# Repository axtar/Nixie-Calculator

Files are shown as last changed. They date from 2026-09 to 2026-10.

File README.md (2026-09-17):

## Nixie Calculator - RPN | Algebraic 

<br>

#### This repository contains some information and ideas for building a nixie calculator and is provided *as-is* for educational, experimental, and hobbyist purposes only. However, this repository is only intended for suitably qualified electronics engineers. The project has not been tested for compliance with electrical, safety, or electromagnetic standards (e.g., CE, FCC). 

##
>[!WARNING]
> 
> #### Nixie tubes and associated circuitry operate at potentially dangerous voltages. If you choose to build or use the calculator, you are doing so at your own risk.

>[!IMPORTANT]
>- **Start with [this document](Docs/README.md).**

>[!NOTE]
> - **The project is not affiliated with any of the service providers mentioned in this repository.**
> - **No HP code was used to develop the RPN firmware.**

##
#### Project Status 
- **Software: ready to be reviewed**
- **Hardware: ready to be reviewed**

#### Project video
https://www.youtube.com/watch?v=CKAuJhKjPZ4

#### Features
-	4 nixie versions: IN-12/IN-15A, IN-16, IN-17 and B-5870
-	alternative 7-segment LED version 
-	2 calculator engines: RPN (reverse polish notation) or algebraic
- 14 digits with decimal points, minus signs and dynamic scientific notation
-	arbitrary-precision arithmetic up to 32 digits (experimental)
-	30+ math operations
-	easy nixie replacement
- LED backlighting/underlighting (nixie versions only)
-	mechanical keyboard with 40 switches
-	custom keycap legends and colors
-	RTC with battery backup
-	clock, stopwatch and timer modes
-	ESP32 based controller board
-	PIR, GPS and temperature sensor module (optional)
-	works with a standard DC 12V/2A regulated power supply (wall wart)
-	3D printed case
-	no network connection is needed; all settings can be adjusted using the keyboard
- Optional web based features: configuration, device mirroring and stack register display
-	open-source firmware

#### RPN IN-16 version
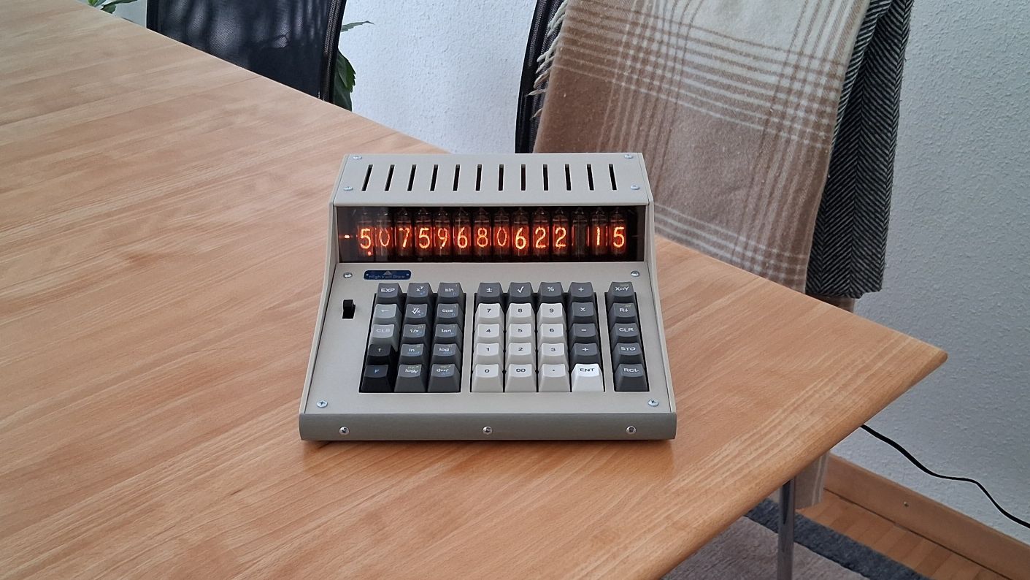
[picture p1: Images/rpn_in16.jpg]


#### RPN IN-17 version
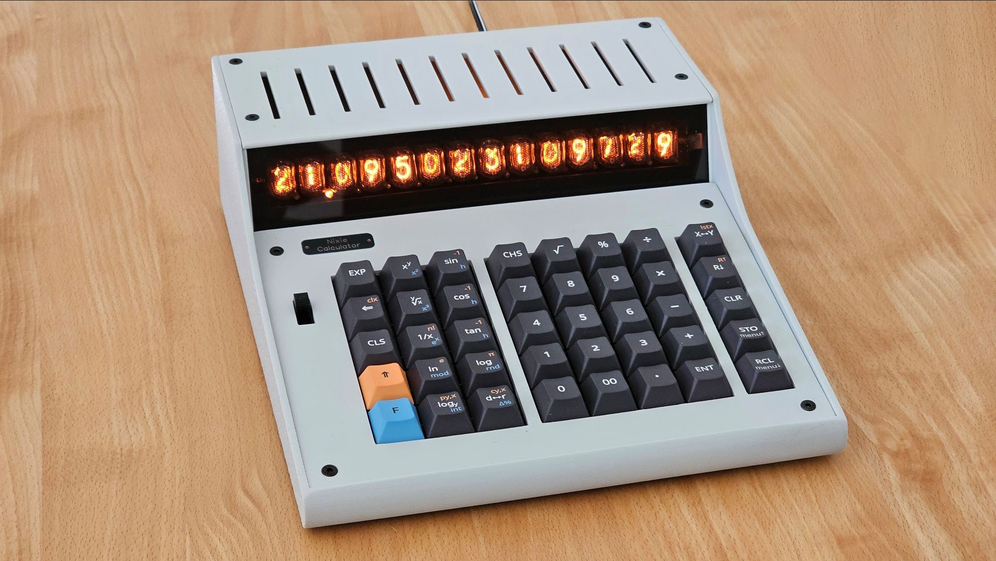
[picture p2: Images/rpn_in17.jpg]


#### RPN 7-seg LED version
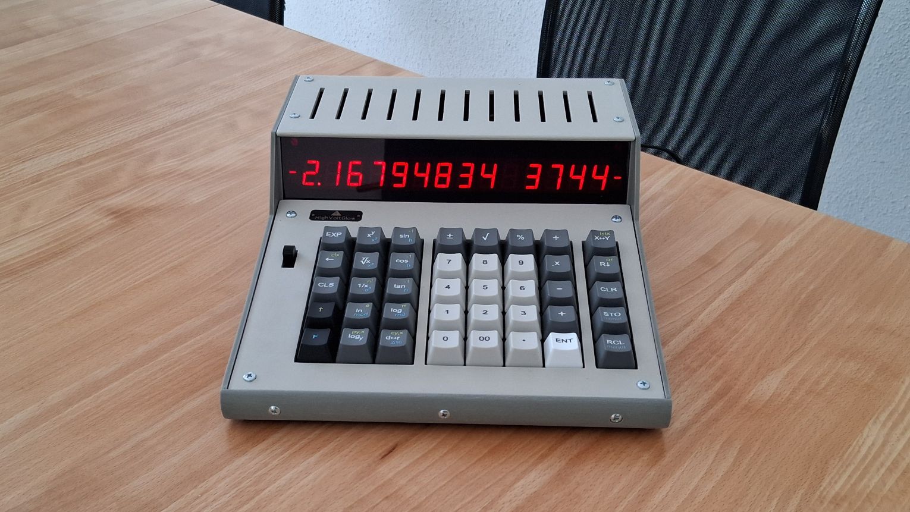
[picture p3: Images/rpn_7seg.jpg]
RPN7SEG


#### RPN IN-12B / IN-15A version
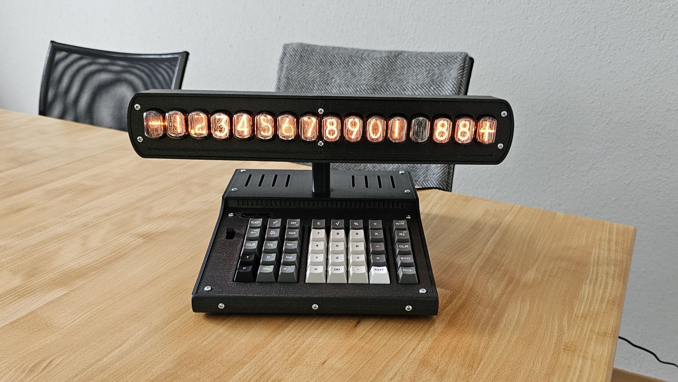
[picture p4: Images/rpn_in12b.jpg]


#### RPN IN-12A / IN-15A version
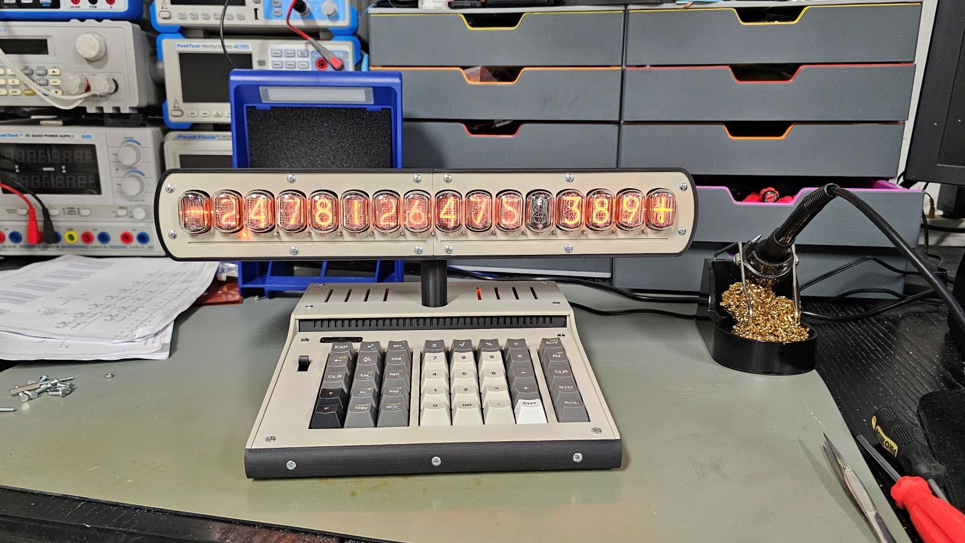
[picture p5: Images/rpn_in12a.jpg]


#### Algebraic B-5870 version with self-printed keycap legends
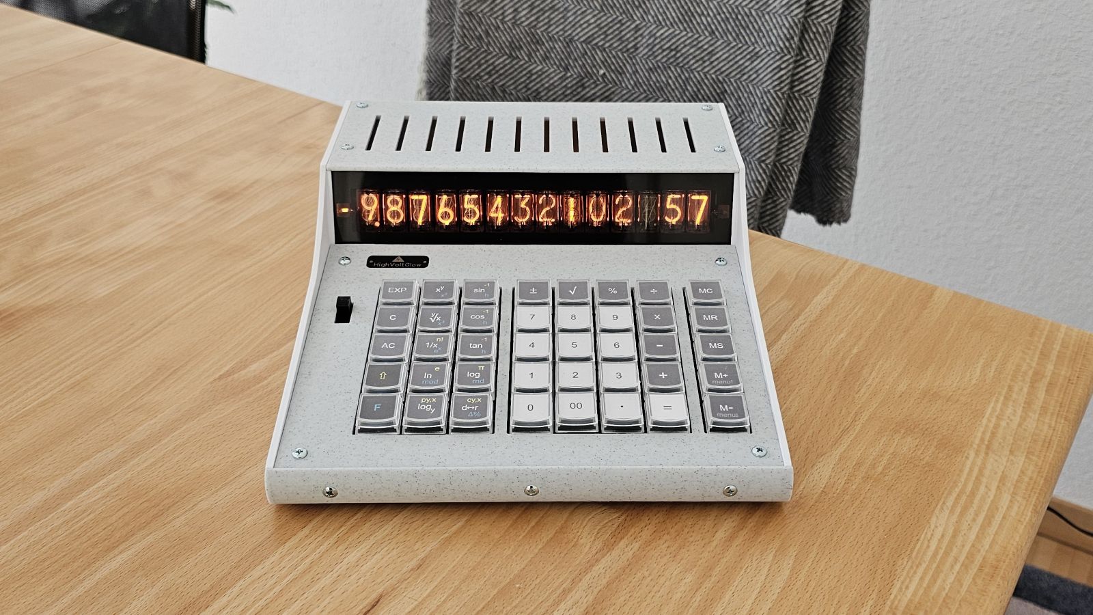
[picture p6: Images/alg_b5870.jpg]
ALGB5870


#### ИН-16 (IN-16) nixie tubes - production probably started in 1972
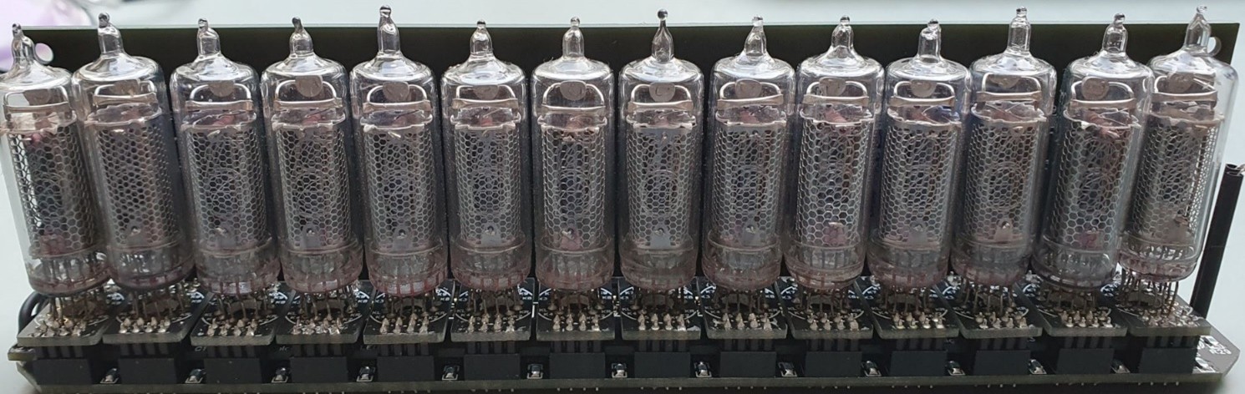
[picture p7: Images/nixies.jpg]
Nixies


#### All nixie versions have LED lighting
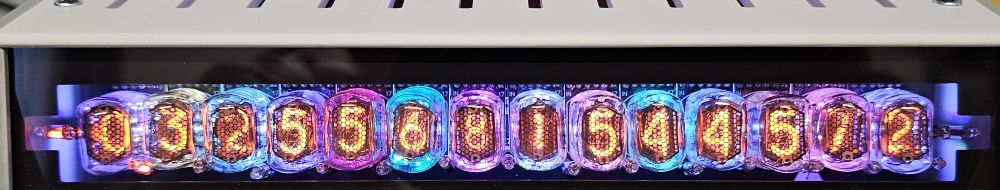
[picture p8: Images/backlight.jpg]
Backlight


#### Controller board with 3D models
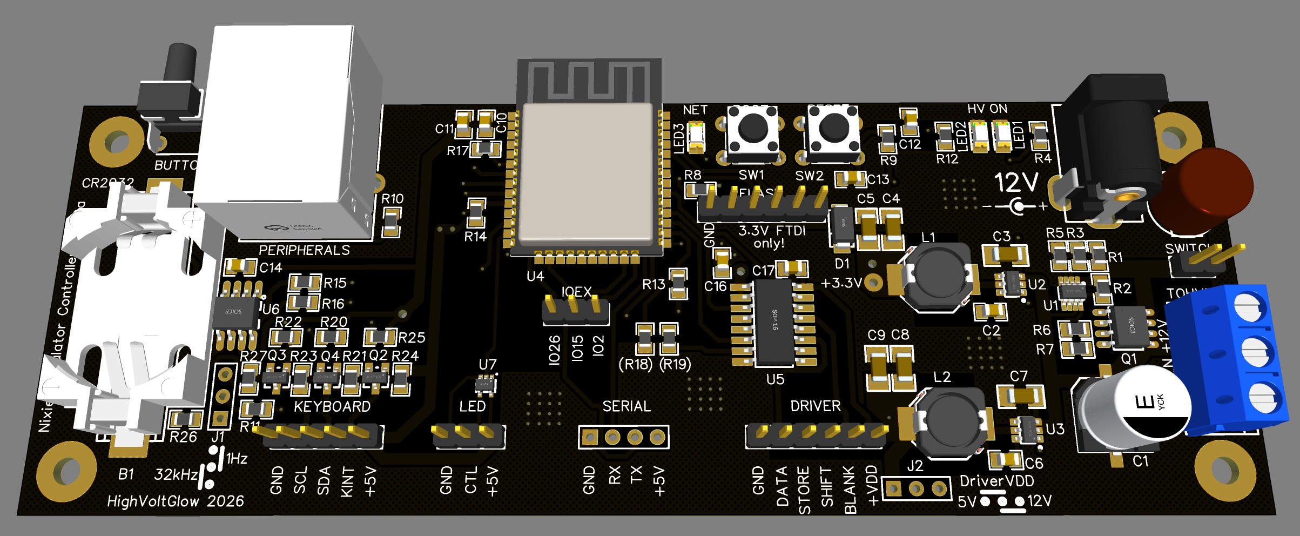
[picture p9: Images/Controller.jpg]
CONTROLLER


#### Exposed RPN keyboard
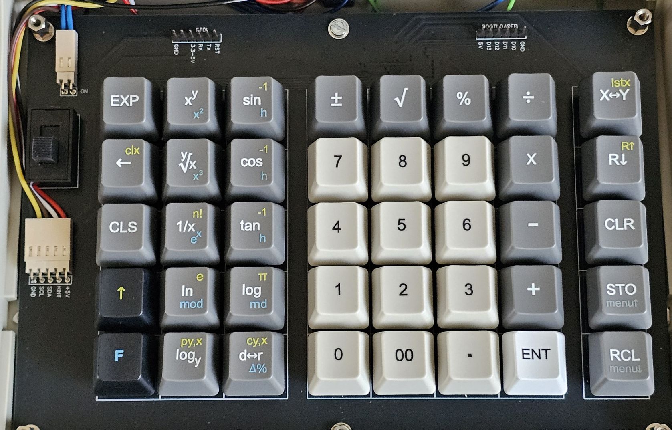
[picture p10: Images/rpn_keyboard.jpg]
KEYBOARD
<br>

##
#### Calculator keypad and stack registers displayed on a smartphone
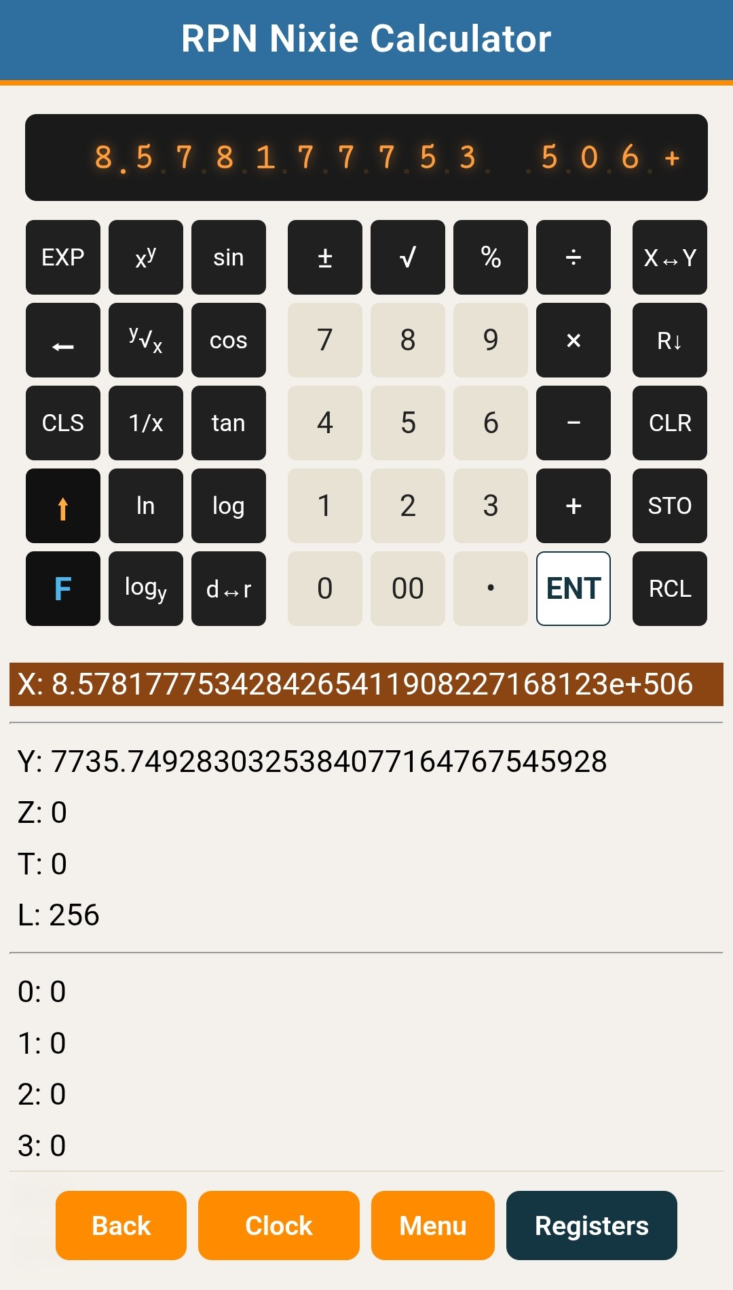
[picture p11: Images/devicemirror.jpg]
<br>

#### The calculator can be configured directly with the keyboard or using the web interface
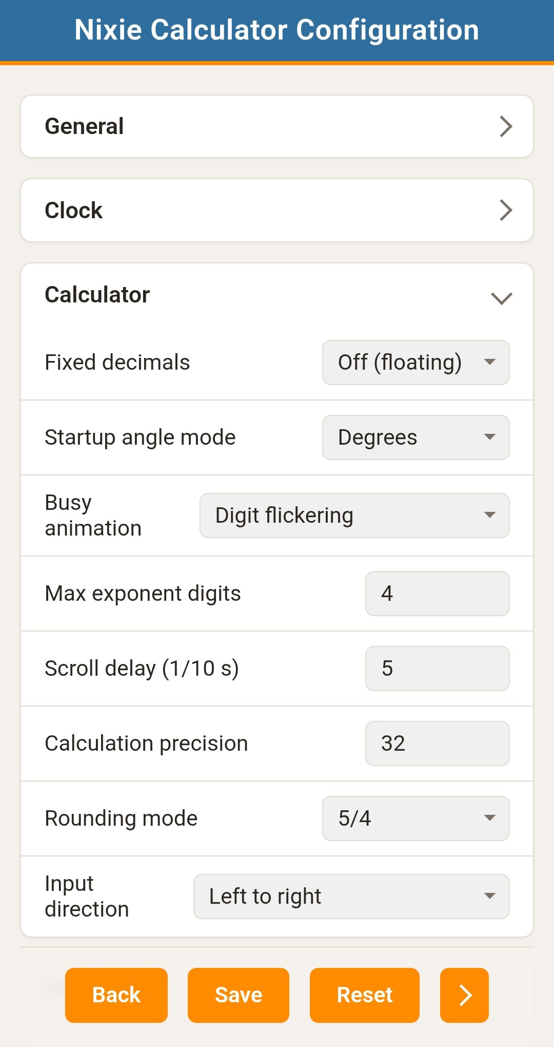
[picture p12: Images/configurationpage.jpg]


#### The status page shows some information about the calculator
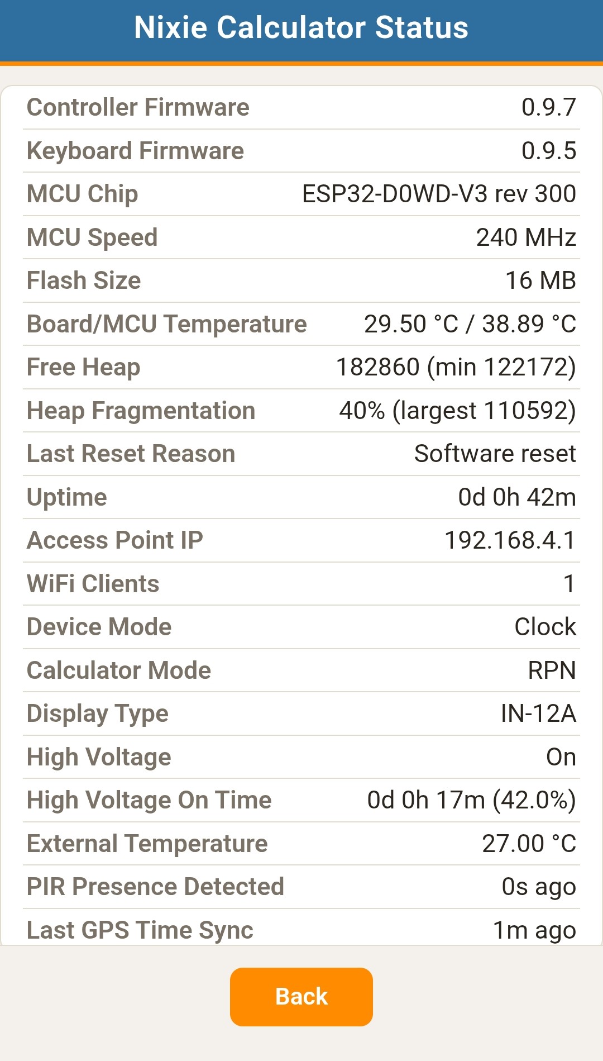
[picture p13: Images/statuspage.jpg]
<br>

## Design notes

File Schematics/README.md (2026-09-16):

>[!NOTE]
> **Please note that each file contains schematics for a single PCB, and the net labels refer only to that specific board. Identical net labels in different files are not necessarily connected.**

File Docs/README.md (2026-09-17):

# Read before you start
#### This repository contains some information and ideas for building a nixie calculator and is provided *as-is* for educational, experimental, and hobbyist purposes only. However, this repository is only intended for suitably qualified electronics engineers. The project has not been tested for compliance with electrical, safety, or electromagnetic standards (e.g., CE, FCC). 

##


#### Nixie tubes and associated circuitry operate at potentially dangerous voltages. If you choose to build or use the calculator, you are doing so at your own risk.

##
**Please read all documents in [Docs](../Docs) before deciding whether to build the calculator.**

## Known issues
Currently no known issues<br>
~~The recently added nixie dimming function has been disabled in versions IN-12A and IN-12B due to flickering of the LED lighting.~~ fixed :white_check_mark:

## Documentation guide

[Assembling the PCBs](Assembling%20the%20PCBs.pdf)

Not a guide but some important information about assembling the PCBs

[Assembling the calculator - 7-seg LED - version](Assembling%20the%20calculator%20-%207-seg%20LED%20-%20version.pdf)

Step-by-step assembly guide for the 7-seg LED calculator version

[Assembling the calculator - IN-12 - version](Assembling%20the%20calculator%20-%20IN-12%20-%20version.pdf)

Step-by-step assembly guide for the IN-12 calculator version

[Assembling the calculator - IN-16 - B-5870 - IN-17 - versions](Assembling%20the%20calculator%20-%20IN-16%20-%20B-5870%20-%20IN-17%20-%20versions.pdf)

Step-by-step assembly guide for the IN-16 - B-5870 - IN-17 - calculator versions

[Assembling the peripherals module](Assembling%20the%20peripherals%20module.pdf)

Step-by-step assembly guide for the optional peripherals-module

[Flashing the bootloader and the firmware](Flashing%20the%20bootloader%20and%20the%20firmware.pdf)

Step-by-step guide for burning the bootloader of the keyboard MCU as well as flashing the keyboard and controller firmware

[Gerber and EasyEDA project files](Gerber%20and%20EasyEDA%20project%20files.pdf)

Some information about the PCB files

[High Voltage Power Supply](High%20Voltage%20Power%20Supply.pdf)

Recommendations for the nixie power supply

[Keyboard layout and keycaps](Keyboard%20layout%20and%20keycaps.pdf)

Shows the RPN and ALG keyboard layouts and contains information on how to obtain the custom keycaps

[Mounting the nixies](Mounting%20the%20%20nixies.pdf)

Step-by-step guide for mounting and soldering the nixie tubes

[Nixie Calculator User Manual (Algebraic)](Nixie%20Calculator%20User%20Manual%20(Algebraic).pdf)

Complete user manual for the algebraic version of the calculator

[Nixie Calculator User Manual (RPN)](Nixie%20Calculator%20User%20Manual%20(RPN).pdf)

Complete user manual for the RPN version of the calculator

[PCB List](PCB%20List.pdf)

Contains a list of PCBs required for the different versions of the calculator

[Printing the case](Printing%20the%20case.pdf)

Contains a list of 3D printed parts required for the different versions of the calculator as well as information on printing and post-processing the parts

[How to build the keyboard firmware](/Firmware/Keyboard/README_HowToBuild.md)

Short guide on how to build the keyboard firmware

[How to build the controller firmware](/Firmware/Controller/README_HowToBuild.md)

Short guide on how to build the controller firmware

## How to approach this project
Consider building the 7-segment LED version first. If you later decide to build a nixie version you can reuse the keyboard and the controller.

I recommend following this order:
1. Read the documentation (and use it to implement the next steps).
2. Build the keyboard firmware.
3. Build the controller firmware.
4. Assemble the controller board and flash the firmware. 
5. Assemble the keyboard, burn the bootloader and flash the firmware.
6. Assemble the display board(s).
7. If building a nixie version use a commercial nixie power supply (recommended) or assemble the HV PSU board (experimental).
8. Complete the wiring of the device.
9. Test the device.
10. Print the case and complete the assembly of the calculator.

## AI
I started using AI in this project because I wanted to add some additional web-based features to the calculator, and I don't enjoy web design. 
The last AI-free firmware version was 0.1.11 from August 2026, which already included most of the functionality, including a web-based register display.
AI was primarily used to assist with the web interface and to generate the test cases.

## Web server and OTA (over-the-air) firmware update
The calculator can be configured and used without a network connection. If you don't like network and web-based features in a retro project you can just change the defines to
``` C++
#define WEB_SUPPORT false
#define OTA_SUPPORT false
```
in the Config.h file and the network-based stuff will be ignored during compilation. If you want to use the the web interface but you don't like the OTA update feature, set the defines to
``` C++
#define WEB_SUPPORT true
#define OTA_SUPPORT false
```

## Internet connection
Since the time can be set manually and synchronized with the browser time or a GPS module, I will not implement an internet connection for NTP synchronization. I may be wrong, but securely managing passwords for third-party access points requires, in addition to firmware and NVS encryption (including fuse burning), a secure browser connection with valid certificates to avoid browser warnings. I don't feel like dealing with all that stuff.
## Device mirroring
The device can be mirrored using a browser. Device mirroring is WebSocket based and is bidirectional as there is also a virtual keyboard. Actions on the calculator are reflected in the browser and vice versa. Please note that the updates sent to the browser are throttled to avoid potential WebSocket flooding, for example, in stopwatch mode. 

## About the experimental arbitrary-precision arithmetic
The arbitrary-precision arithmetic used in the calculator is based on the ratpak library. It’s experimental because I had to make changes to run the code on an ESP32 and fix some memory leaks, rounding problems and faulty formatting routines.

Calculations with very big numbers can be slow. For example, calculating the square root of 9e+9999 with a precision of 32 digits takes about 7 seconds. For calculations in the more common range between 1e+99 and 1e-99, the result is usually displayed immediately. One exception is the calculation of non-integer factorials where a gamma function approximation is used.

The precision of the calculations and the internal registers has been set to 32 as a compromise between accuracy and performance.

The decision to use arbitrary-precision arithmetic was motivated by the fun of learning something new and by the poor precision of the 64-bit floating-point arithmetic. Just an example: if you calculate 1.0000000000001 ^ 999 using the C/C++ pow function you will get 1.00000000009982 instead of 1.00000000009990.

## Precision of timer, stopwatch and clock

The precision of the timer and stopwatch depends on the internal MCU oscillator. It is possible to connect the (probably) more precise 32kHz clock signal of the RTC chip to the ESP32, but I have no plans to implement this change in the firmware. If no GPS module is connected, the clock depends on the accuracy of the RTC chip.

## Nixies

To extend the lifespan of the nixie tubes, it’s recommended to use the auto-off function or to connect the peripherals module for presence detection (PIR). It’s also recommended to use the cathode poisoning prevention function. This is especially important for the IN-15A symbol nixies which only display + and -. I don't know whether dimming or cross-fading can negatively affect the lifespan of nixie tubes.

## Firmware development tools

I use VS Code and the ESP-IDF extension with arduino-esp32 as a component to develop the firmware for the controller (ESP32). For the keyboard firmware (ATmega328P) I use the Arduino IDE.

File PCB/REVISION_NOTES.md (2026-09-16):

# PCB revision notes
## Controller
### Revision 2a
- The BSS138-based level-shifter for LED control was replaced by a 74LV1T34 single-voltage translation buffer, which is apparently better suited for this task.
- The current limiting resistor values of the control LEDs have been increased.
---

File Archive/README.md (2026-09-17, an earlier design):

>[!NOTE]
> **The archive directory contains older files that are worth keeping, as I rebuild the repository from time to time to get rid of deprecated stuff and reduce the footprint.**
>
> Just as an example, I wanted to keep the controller firmware V0.1.11, as this was the last AI-free version.

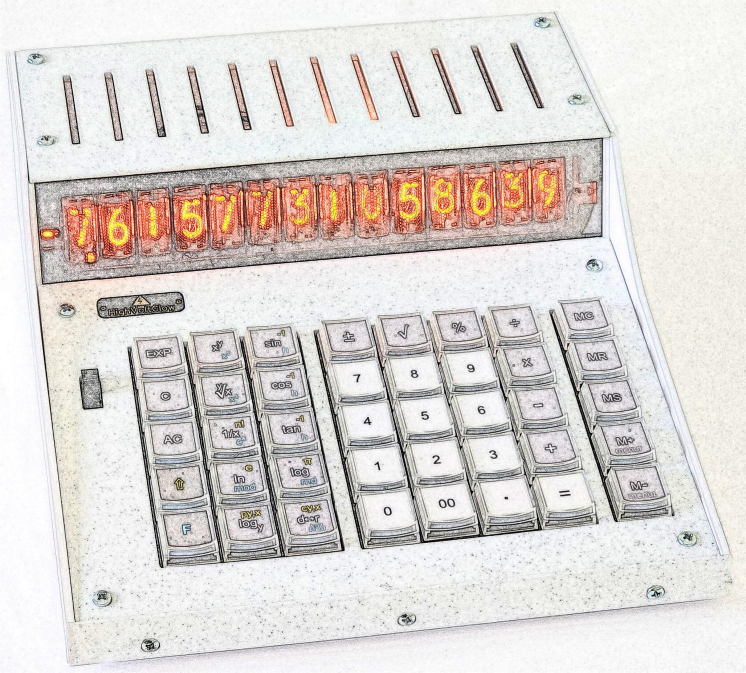
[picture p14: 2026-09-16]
Images/nixie_calculator_algebraic_cover.png

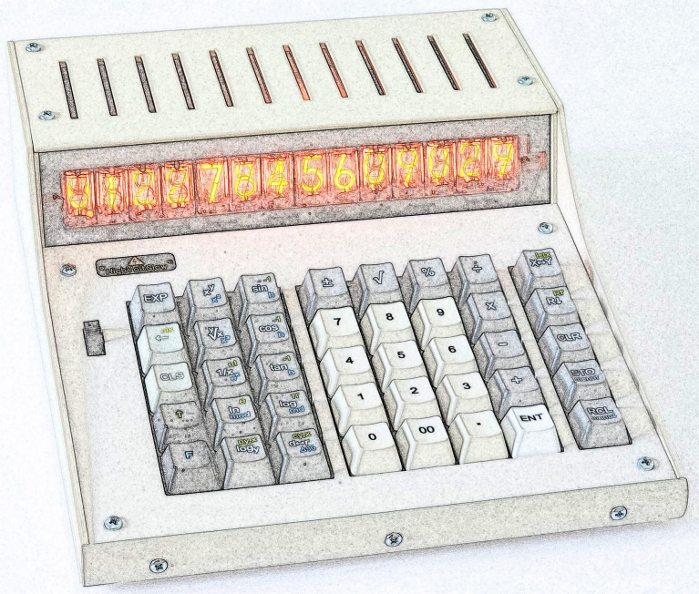
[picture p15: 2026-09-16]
Images/nixie_calculator_rpn_cover.png

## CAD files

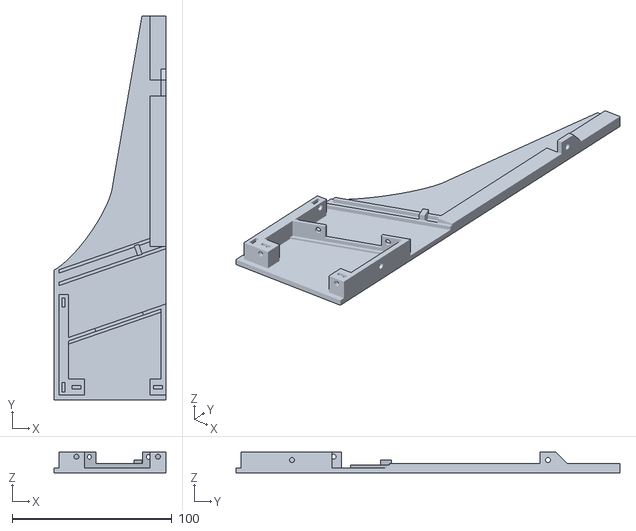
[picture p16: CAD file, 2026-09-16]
3DPrints/STL/Nixie Calculator IN-17 Right for Frame.stl
70.0 x 240.0 x 13.0

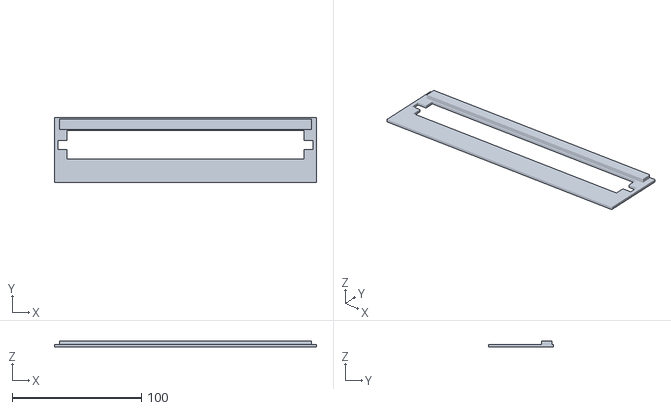
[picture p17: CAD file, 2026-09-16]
3DPrints/STL/Nixie Calculator B-5870 Display Frame.stl
203.0 x 50.0 x 5.00

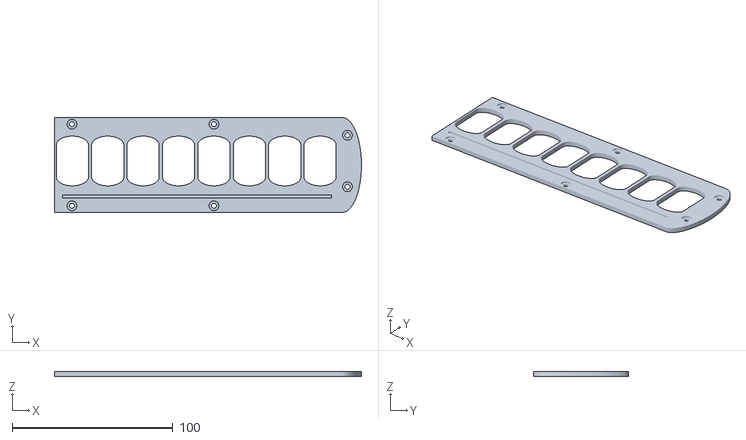
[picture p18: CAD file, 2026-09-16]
3DPrints/STL/Nixie Calculator IN-12B Display Front Right V2.stl
190.8 x 59.0 x 3.00

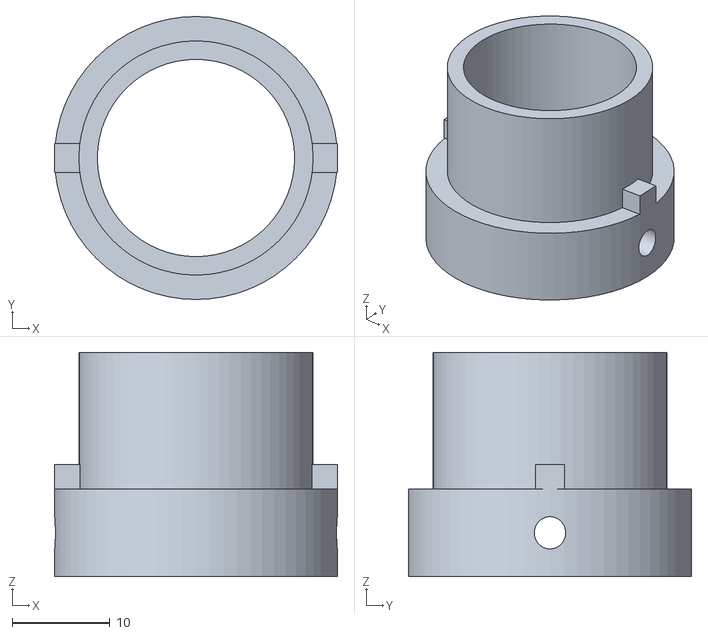
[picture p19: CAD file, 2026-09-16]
3DPrints/STL/Nixie Calculator IN-12 Tube Holder Part 1.stl
29.0 x 29.0 x 23.0

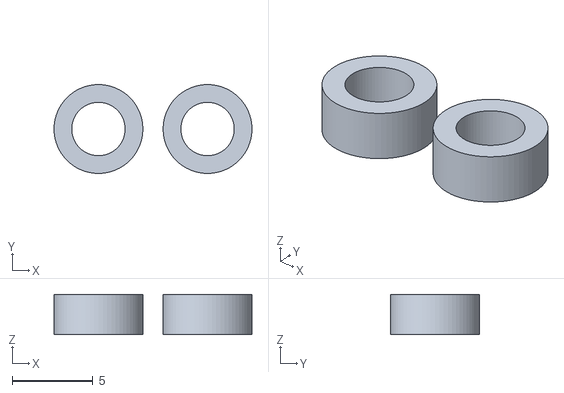
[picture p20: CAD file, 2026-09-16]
3DPrints/STL/Nixie Calculator LED Board Spacers.stl
12.2 x 5.50 x 2.50

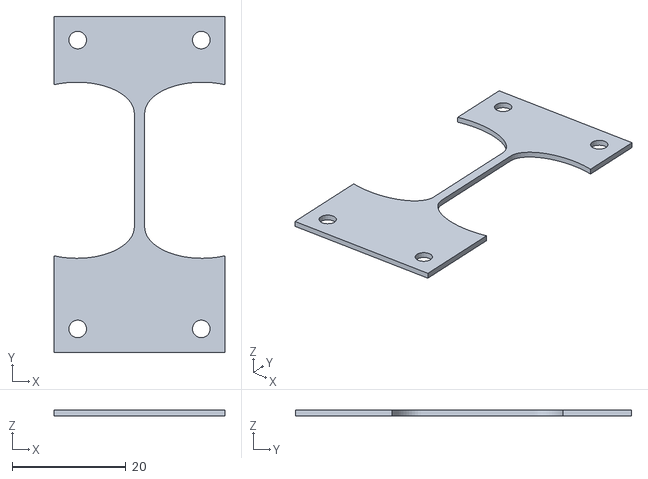
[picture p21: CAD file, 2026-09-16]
3DPrints/STL/Nixie Calculator IN-12B Display Gap Cover.stl
30.0 x 59.0 x 1.00

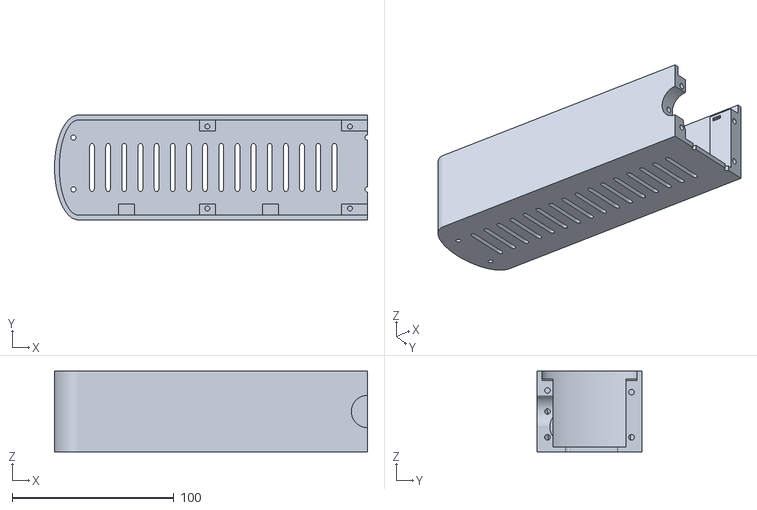
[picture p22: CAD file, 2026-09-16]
3DPrints/STL/Nixie Calculator IN-12 Display Left V2.stl
193.7 x 65.0 x 50.0

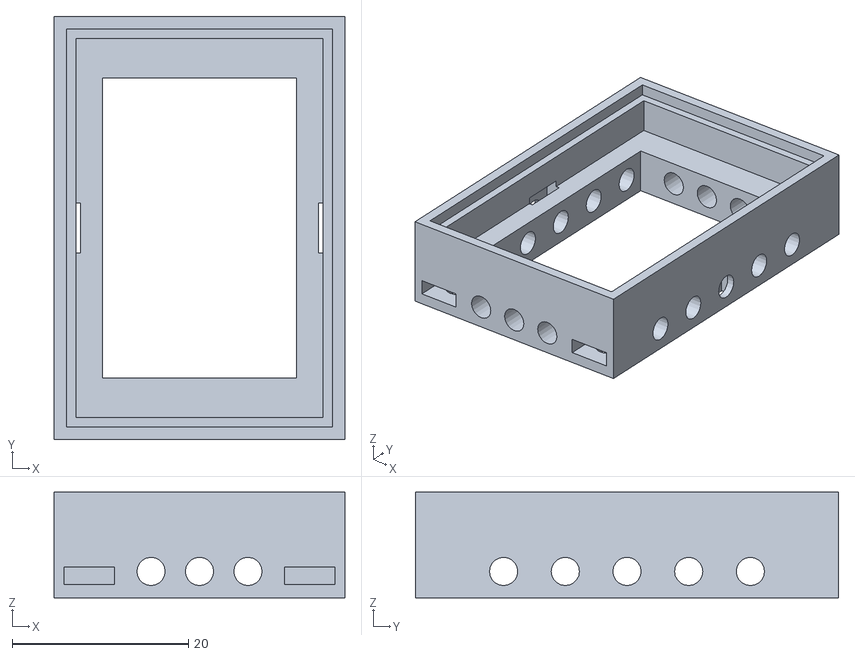
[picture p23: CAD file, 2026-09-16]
3DPrints/STL/HVFIX Part 1.stl
33.0 x 48.0 x 12.0

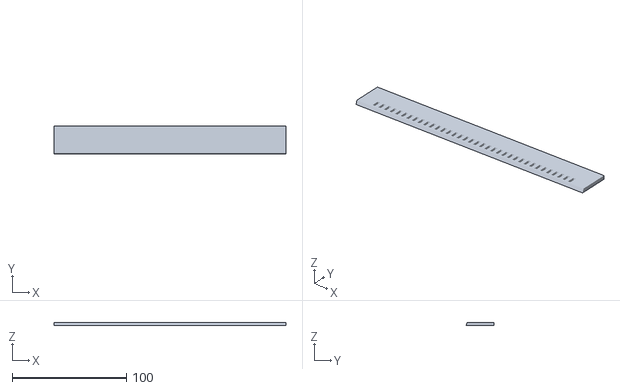
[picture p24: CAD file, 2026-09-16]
3DPrints/STL/Nixie Calculator IN-12 Front Panel.stl
203.0 x 24.6 x 3.00

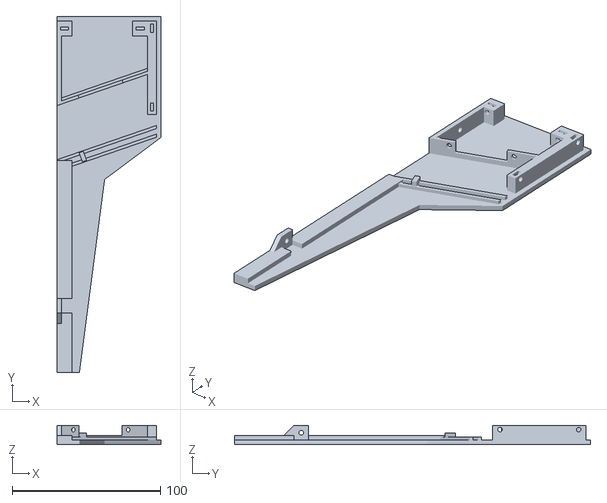
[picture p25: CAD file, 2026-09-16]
3DPrints/STL/Nixie Calculator 7segLED Right.stl
70.0 x 240.0 x 13.0

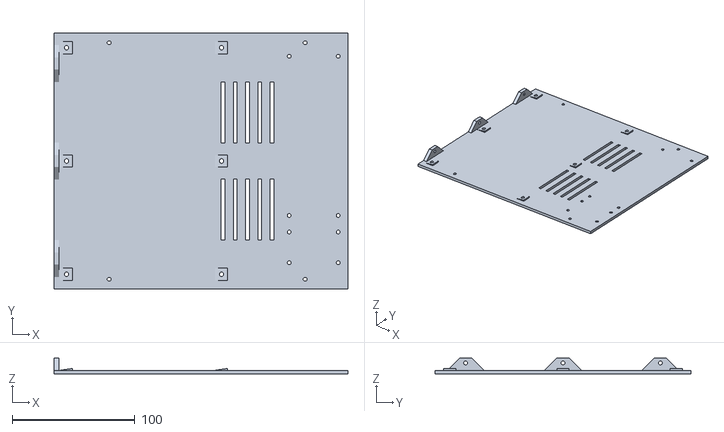
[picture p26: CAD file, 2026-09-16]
3DPrints/STL/Nixie Calculator Bottom.stl
240.0 x 209.0 x 13.0

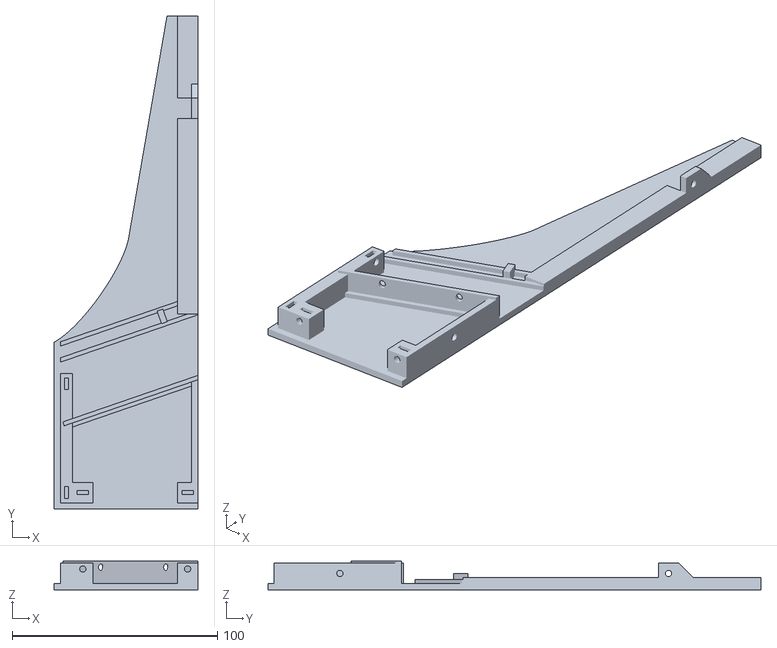
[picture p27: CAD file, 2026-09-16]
3DPrints/STL/Nixie Calculator IN-16 Right for Frame.stl
70.0 x 240.0 x 14.0

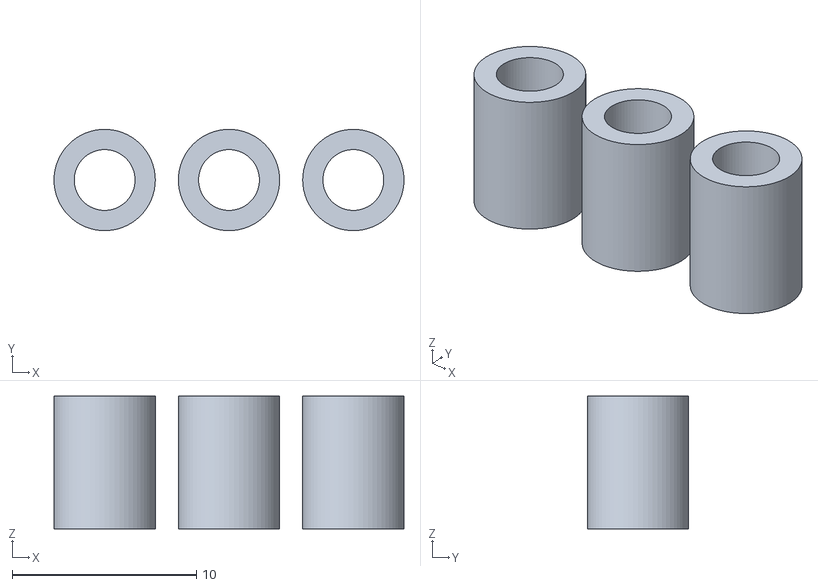
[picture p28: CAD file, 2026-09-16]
3DPrints/STL/Nixie Calculator IN-12 LED Board Spacers.stl
19.0 x 5.50 x 7.20

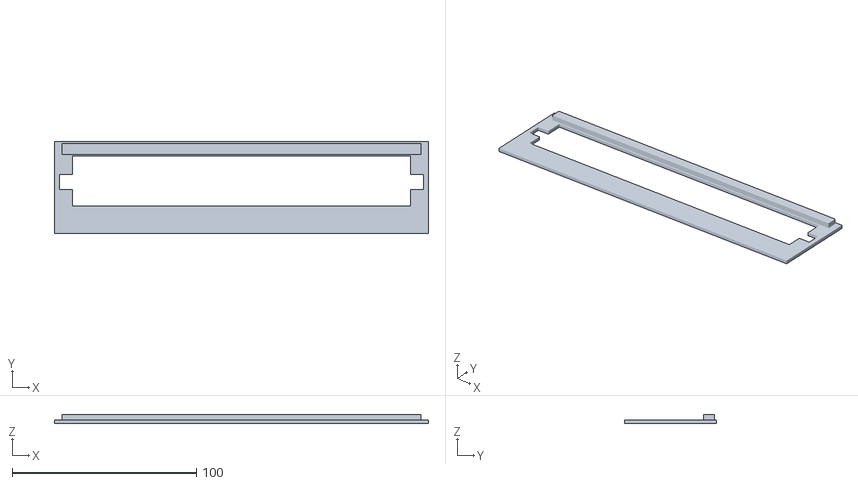
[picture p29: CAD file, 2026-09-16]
3DPrints/STL/Nixie Calculator IN-16 Display Frame.stl
203.0 x 50.0 x 5.00

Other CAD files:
3DPrints/STL/Nixie Calculator IN-12A Display Front 3mm Left V2.stl
3DPrints/STL/Nixie Calculator IN-17 Left for Frame.stl
3DPrints/STL/Nixie Calculator IN-12 Bottom.stl
3DPrints/STL/Nixie Calculator IN-12 Display Right V2.stl
3DPrints/STL/HVFIX Part 2.stl
3DPrints/STL/Nixie Calculator 7segLED Left.stl
3DPrints/STL/Nixie Calculator B-5870 Socket Cover.stl
3DPrints/STL/Nixie Calculator Back Shield.stl
3DPrints/STL/Nixie Calculator Front V2.stl
3DPrints/STL/Nixie Calculator IN-12 Back Shield.stl
3DPrints/STL/Nixie Calculator IN-12 Left.stl
3DPrints/STL/Nixie Calculator IN-12 Right.stl
3DPrints/STL/Nixie Calculator IN-12 Top.stl
3DPrints/STL/Nixie Calculator IN-12 Tube Holder Part 2.stl
3DPrints/STL/Nixie Calculator IN-12 Union Tube V2.stl
3DPrints/STL/Nixie Calculator IN-12A Display Front 3mm Right V2.stl
3DPrints/STL/Nixie Calculator IN-12A Display Front 4mm Left V2.stl
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

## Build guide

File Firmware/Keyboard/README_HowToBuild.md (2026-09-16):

## How to build the keyboard firmware
### With VS Code and PlatformIO extension:
- Download the calculator repository and unzip it into your project directory
- Open the Firmware/Keyboard/PlatformIO folder in VS Code
- If you trust the contents of the folder, set the folder to trusted
- Build the project
### With Arduino IDE:
- Download the calculator repository and unzip it into your project directory
- Open the Firmware/Keyboard/ArduinoIDE/Keyboard/Keyboard.ino file in the Arduino IDE
- Add the "Keypad" library using the library manager or from https://github.com/Chris--A/Keypad
- Select the "Arduino Uno" board
- Verify/Compile the sketch

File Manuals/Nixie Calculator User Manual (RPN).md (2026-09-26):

# Nixie Calculator User Manual (RPN Version)

*September 26, 2026 — Draft - Version 0.14*

## Table of Contents

- [General information](#general-information)
- [Power supply](#power-supply)
- [Power on / Power off](#power-on--power-off)
- [The \[F\] key](#the-f-key)
- [The \[↑\] key](#the--key)
- [Calculator mode](#calculator-mode)
- [Clock mode](#clock-mode)
  - [Entering date and time](#entering-date-and-time)
  - [Clock modes](#clock-modes)
  - [Timer](#timer)
  - [Stopwatch](#stopwatch)
- [Menu mode](#menu-mode)
  - [Navigation](#navigation)
  - [Settings table](#settings-table)
- [Reducing the display on-time](#reducing-the-display-on-time)
- [Web server](#web-server)
- [Peripherals module](#peripherals-module)
- [Reset SSID and passwords](#reset-ssid-and-passwords)
- ["Factory" reset](#factory-reset)
- [OTA firmware update](#ota-firmware-update)
- [Troubleshooting](#troubleshooting)
- [Table of shortcuts](#table-of-shortcuts)
- [List of error codes](#list-of-error-codes)
- [List of operations](#list-of-operations)

## General information

Apart from the power supply, the nixie calculator works completely independently and requires neither a network connection nor any peripheral devices.

This manual does not describe how to use an RPN calculator. There are numerous tutorials available online.

Just this: to calculate 1 + 2 type `[1] [ENT] [2] [+]`

## Power supply

The calculator needs a DC 12V/2A regulated power supply with a center positive barrel jack plug (5.5/2.1mm compatible).

## Power on / Power off

Use the power switch to the left of the keyboard to power on and off the calculator. During start-up, the calculator briefly shows the controller firmware version on the left and the keyboard firmware version on the right. By default, the calculator starts in calculator mode.

## The [F] key

The [F] key has several functions:

- Press and release the [F] key to switch between the calculator and the clock mode and to leave the menu mode.
- Hold the [F] key for 3 seconds to enter the menu mode.
- Press the [F] key + an operator key to access the lower functions in calculator mode, for example x²
- Press the [F] key + some defined keys to get a shortcut for some settings, for example LED lighting (see [Table of shortcuts](#table-of-shortcuts)).

## The [↑] key

Press the [↑] key + an operator key to access the upper functions in calculator mode, for example n!

## Calculator mode

In this mode the device works like an RPN calculator (see [List of operations](#list-of-operations)). However, be aware that the arbitrary-precision arithmetic used by the calculator is experimental.

The precision of the calculations and of the internal registers has been set to 32 as a compromise between accuracy and performance. Some calculations with very big numbers can be slow. Exponents can be entered and displayed between -9999 and 9999.

If an error occurs (e.g. overflow, domain, divide by zero), an error code is shown in the center of the display (see [List of error codes](#list-of-error-codes)).

## Clock mode

### Entering date and time

In clock modes (0-9) press the [CLS] key. A blinking zero indicates that you can enter the date and the time in the YYYYMMDDhhmmss format. The [←] key deletes the last entered digit. Press [ENT] to confirm or [CLS] to abort.

### Clock modes

There are several clock modes. They can be accessed directly with the [0] to [9] keys. The stopwatch mode can be accessed directly using the [00] key and the timer mode using the [.] key.

**Clock modes**

| Mode | Description |
| --- | --- |
| 0 | time only |
| 1 | time with no seconds |
| 2 | moving time |
| 3 | time or date |
| 4 | time and date |
| 5 | time and temperature |
| 6 | time and date and temperature |
| 7 | time with hundredths of a second |
| 8 | dual time |
| 9 | raw date and time |

**Special clock modes**

| Mode | Description |
| --- | --- |
| 10 | timer |
| 11 | stopwatch |

### Timer

In timer mode press the [CLS] key. A blinking zero indicates that you can enter the number of days, hours, minutes, and seconds in the format DDhhmmss. The [←] key deletes the last entered digit. Press [ENT] to confirm or [CLS] to abort. Press [ENT] to start and stop the timer. Press [←] to reset the timer. Blinking LEDs indicate the end of the countdown; there is no sound. The flashing can be stopped by pressing the [CLS] key. The accuracy depends on the internal MCU oscillator.

### Stopwatch

In stopwatch mode press the [ENT] key to start the stopwatch. Press [ENT] to pause the display while the stopwatch keeps running. Press [←] to reset the stopwatch. The accuracy depends on the internal MCU oscillator.

## Menu mode

Hold the [F] key for 3 seconds to enter the menu mode. The setting ID (see [Settings table](#settings-table)) is displayed on the left, the setting value(s) on the right. Key autorepeat is enabled in menu mode and starts after 1 second. The autorepeat speed increases after some time. Press the [F] key to leave the menu mode and store the values.

### Navigation

| Keys | Description |
| --- | --- |
| [STO] | Next setting |
| [RCL] | Previous setting |
| [+] | Next value |
| [-] | Previous value |
| [ENT] | Accept value and move to the next column if any |
| [←] | Restore to previously stored value |
| [CLS] | Reset to default value |
| [F] + [CLR] | Reset all settings to default |
| [F] + [CLS] | Exit menu mode and discard changes |
| [F] | Exit menu mode and commit changes |

### Settings table

| ID | Name | Description | Values |
| --- | --- | --- | --- |
| 1 | startupmode | Start in calculator or in clock mode | 0 = calculator (default)<br>1 = clock |
| 2 | showversion | Show version at startup | 0 = off<br>1 = on (default) |
| 3 | autooffmode | Auto off action after a period of no keyboard activity | 0 = auto off disabled<br>1 = shutdown high voltage<br>2 = switch to clock mode (default) |
| 4 | autooffdelay | Delay in minutes for auto off mode | 1 - 720 (default 5) |
| 5 | offstarttime | Start time of the scheduled high voltage shutdown | 00:00 - 23:59 (default 00:00) |
| 6 | offstoptime | Stop time of the scheduled high voltage shutdown | 00:00 - 23:50 (default 00:00) |
| 7 | offdays | Days of the week the high voltage is off for the entire day | 0 = none (default) [bitmask] |
| 8 | clockmode | Initial clock mode | 0 = time (default)<br>1 = time, no seconds<br>2 = moving time<br>3 = time or date<br>4 = time and date<br>5 = time and temperature<br>6 = time and date and temperature<br>7 = time with hundredths of a second<br>8 = dual time<br>9 = raw date and time<br>10 = timer<br>11 = stopwatch |
| 9 | hourmode | 12 or 24 hours mode | 0 = 12 hours<br>1 = 24 hours (default) |
| 10 | leadingzero | Show hours leading zero | 0 = off<br>1 = on (default) |
| 11 | timeseparator | Separator mode in compact time format | 0 = off<br>1 = blink (default)<br>2 = on |
| 12 | timeeffects | Time digit transition effects | 0 = off (default)<br>1 = crossfade<br>2 = rolling 1<br>3 = rolling 2<br>4 = rolling 3 |
| 13 | dateformat | Date format | 0 = ddmmyy (default)<br>1 = yymmdd<br>2 = mmddyy<br>3 = yyddmm |
| 14 | pirmode | Use PIR to reduce the operating time of the nixie tubes | 0 = off (default)<br>1 = on |
| 15 | pirdelay | PIR delay time in minutes before shutting down the high voltage | 1 - 720 (default 5) |
| 16 | gpsmode | Sync with GPS time | 0 = off (default)<br>1 = on |
| 17 | gpsspeed | GPS communication baud rate | 0 = 2400<br>1 = 4800<br>2 = 9600<br>3 = 19200<br>4 = 38400 (default)<br>5 = 57600<br>6 = 115200 |
| 18 | gpssyncinterval | GPS time sync interval in minutes | 1 - 720 (default 10) |
| 19 | temperaturemode | Use temperature sensor | 0 = off (default)<br>1 = on |
| 20 | temperaturecf | Temperature in C or F | 0 = Celsius (default)<br>1 = Fahrenheit |
| 21 | ledmode | LEDs on by time or always * | 0 = time<br>1 = always (default) |
| 22 | ledbrightness | General brightness of the LED lighting in percent * | 5 – 100 (default 100) |
| 23 | calcrgbmode | RGB mode in calculator mode * | 0 = off (default)<br>1 = by content<br>2 = by content (all digits)<br>3 = random (turned on digits only)<br>4 = full random (turned on digits only)<br>5 = fixed color (all digits)<br>6 = random (all digits)<br>7 = full random (all digits)<br>8 = wheel (turned on digits only)<br>9 = wheel (all digits)<br>10 = rainbow (turned on digits only)<br>11 = rainbow (all digits) |
| 24 | clockrgbmode | RGB mode in clock mode * | 0 = off (default)<br>1 = by content<br>2 = random (turned on digits only)<br>3 = full random (turned on digits only)<br>4 = fixed color (all digits)<br>5 = random (all digits)<br>6 = full random (all digits)<br>7 = wheel (turned on digits only)<br>8 = wheel (all digits)<br>9 = rainbow (turned on digits only)<br>10 = rainbow (all digits) |
| 25 | breathingmode | Breathing (pulsing brightness) effect for LED lighting off or on * | 0 = off (default)<br>1 = on |
| 26 | trigcolorchange | Trigger color change for random RGB modes in clock mode * (this setting does not apply to the "moving time" clock mode as the color changes with every movement) | 0 = off (default)<br>1 = every second<br>2 = every minute<br>3 = every hour |
| 27 | ledstarttime | Start time of LED lighting * | 00:00 - 23:59 (default 00:00) |
| 28 | ledstoptime | Stop time of LED lighting * | 00:00 - 23:59 (default 00:00) |
| 29 | ledstarttime2 | Start time of LED lighting * | 00:00 - 23:59 (default 00:00) |
| 30 | ledstoptime2 | Stop time of LED lighting * | 00:00 - 23:59 (default 00:00) |
| 31 | acpstarttime | Start time of cathode poisoning prevention | 00:00 - 23:59 (default 00:00) |
| 32 | acpduration | Duration in minutes of cathode poisoning prevention | 0 - 720 (default 0) |
| 33 | acpforceon | Force turning nixies on during cathode poisoning prevention | 0 = off<br>1 = on (default) |
| 34 | negativecolor | RGB LED color for negative numbers in calculator mode * | 0-255,0-255,0-255 (default 0,0,0) |
| 35 | positivecolor | RGB LED color for positive numbers in calculator mode * | 0-255,0-255,0-255 (default 0,0,0) |
| 36 | errorcolor | RGB LED color for error in calculator mode * | 0-255,0-255,0-255 (default 0,0,0) |
| 37 | negexpcolor | RGB LED color for negative exponents in calculator mode * | 0-255,0-255,0-255 (default 0,0,0) |
| 38 | posexpcolor | RGB LED color for positive exponents in calculator mode * | 0-255,0-255,0-255 (default 0,0,0) |
| 39 | fixedcalccolor | RGB LED fixed color in calculator mode * | 0-255,0-255,0-255 (default 0,0,0) |
| 40 | timecolor | RGB LED color for time in clock mode * | 0-255,0-255,0-255 (default 0,0,0) |
| 41 | timecolor2 | RGB LED color for dual time in clock mode * | 0-255,0-255,0-255 (default 0,0,0) |
| 42 | datecolor | RGB LED color for date in clock mode * | 0-255,0-255,0-255 (default 0,0,0) |
| 43 | tempcolor | RGB LED color for temperature in clock mode * | 0-255,0-255,0-255 (default 0,0,0) |
| 44 | fixedcolor | RGB LED fixed color in clock mode * | 0-255,0-255,0-255 (default 0,0,0) |
| 45 | dstweek | Daylight saving time change, week of month | 1 = first<br>2 = second<br>3 = third<br>4 = fourth<br>5 = last (default) |
| 46 | dstdow | Daylight saving time change, day of week | 0 = sunday (default) - 6 = saturday |
| 47 | dstmonth | Daylight saving time change, month | 0 = jan - 11 = dec (default 2 = mar) |
| 48 | dsthour | Daylight saving time change, hour | 0 - 23 (default 2) |
| 49 | dstoffset | Daylight saving time change, offset to UTC in minutes | -720 - 840 (default 120) |
| 50 | stdweek | Standard time change, week of month | 1 = first<br>2 = second<br>3 = third<br>4 = fourth<br>5 = last (default) |
| 51 | stddow | Standard time change, day of week | 0 = sunday (default) - 6 = saturday |
| 52 | stdmonth | Standard time change, month | 0 = jan - 11 = dec (default 9 = oct) |
| 53 | stdhour | Standard time change, hour | 0 - 23 (default 3) |
| 54 | stdoffset | Standard time change, offset to UTC in minutes | -720 - 840 (default 60) |
| 55 | dstweek2 | Dual time daylight saving time change, week of month | 1 = first<br>2 = second<br>3 = third<br>4 = fourth<br>5 = last (default) |
| 56 | dstdow2 | Dual time daylight saving time change, day of week | 0 = sunday (default) - 6 = saturday |
| 57 | dstmonth2 | Dual time daylight saving time change, month | 0 = jan - 11 = dec (default 2 = mar) |
| 58 | dsthour2 | Dual time daylight saving time change, hour | 0 - 23 (default 2) |
| 59 | dstoffset2 | Dual time daylight saving time change, offset to UTC in minutes | -720 - 840 (default 0) |
| 60 | stdweek2 | Dual time standard time change, week of month | 1 = first<br>2 = second<br>3 = third<br>4 = fourth<br>5 = last (default) |
| 61 | stddow2 | Dual time standard time change, day of week | 0 = sunday (default) - 6 = saturday |
| 62 | stdmonth2 | Dual time standard time change, month | 0 = jan - 11 = dec (default 9 = oct) |
| 63 | stdhour2 | Dual time standard time change, hour | 0 - 23 (default 3) |
| 64 | stdoffset2 | Dual time standard time change, offset to UTC in minutes | -720 - 840 (default 0) |
| 65 | gpsnotifysync | Notify GPS time sync with a short LED flash * | 0 = off (default)<br>1 = on |
| 66 | gpssynccolor | RGB LED color for notifying GPS time sync * | 0-255,0-255,0-255 (default 255,0,0) |
| 67 | notifytimer | Notify end of timer with flashing LEDs * | 0 = off<br>1 = on (default) |
| 68 | timercolor | RGB LED color for notifying end of timer * | 0-255,0-255,0-255 (default 255,255,255) |
| 69 | fixeddecimals | Number of fixed decimals | 0 = floating (default)<br>1 - 8 = number of fixed decimals |
| 70 | anglemode | Startup angle mode | 0 = degrees (default)<br>1 = radians |
| 71 | showbusycalc | Show animation during long calculations | 0 = off<br>1 = moving decimal point (default)<br>2 = digit flickering |
| 72 | maxexplength | Max length of the exponent | 2 - 4 (default 4) |
| 73 | scrolldelay | Interval while scrolling result in 1/10 seconds | 1 - 20 (default 5) |
| 74 | precision | Calculator precision (restart needed) | 20 - 32 (default 32) |
| 75 | roundingmode | Rounding mode for displaying results | 0 = 5/4 (default)<br>1 = cut |
| 76 | calcinputdirec | Calculator input direction and output format | 0 = left to right (default)<br>1 = right to left<br>2 = right to left with zero padding |
| 77 | inputblinking | Blinking behavior during time, timer and menu value input | 0 = off<br>1 = on (default) |
| 78 | brightness | Display brightness: 15 disables PWM dimming on nixie displays | 1 - 15 (default 15) |
| 79 | dimbrightness | Display brightness during the dimming period | 1 - 15 (default 1) |
| 80 | dimlbrightness | LED lighting brightness in percent during the dimming period * | 5 - 100 (default 20) |
| 81 | dimstarttime | Start time of display dimming | 00:00 - 23:59 (default 00:00) |
| 82 | dimstoptime | Stop time of display dimming | 00:00 - 23:59 (default 00:00) |
| 83 | apautostart | Enable the access point and the web server at startup ** | 0 = off (default)<br>1 = on |
| 84 | rtcdriftcorr | RTC drift compensation in seconds per month | -60 - 60 (default 0) |
| 85 | exttempcorr | External temperature sensor correction in 0.1 °C | -100 - 100 (default 0) |

*(\*) not available for 7-segment LED version*
*(\*\*) only available if WEB_SUPPORT is set to true*

## Reducing the display on-time

There are various settings available to reduce the time the display remains on. The best method is to connect the PIR module and define "pirmode" and "pirdelay" so that the display turns on only when someone is present. There are also some very basic scheduling features. You can set "autooffmode" to "on", and the display will then turn off after a specified period ("autooffdelay") of no keyboard activity. Additionally, the "offstarttime" and "offendtime" settings allow you to define a daily time window during which the display remains off. You can also use the "offdays" setting to specify days of the week (e.g., Saturday and Sunday) on which the display remains off all day. You always can temporarily turn on the display by pressing a key.

## Web server

If enabled in the firmware, press [F] + [ENT] to start an ESP32 Wi-Fi access point (AP) and a web server. After starting, the IP address of the server is displayed for 2 seconds and the network activity LED lights up. By default, the IP address is 192.168.4.1. You can now connect with a smartphone or a PC to this AP and open the site (http://192.168.4.1) with a browser.

- **[Calculator]** shows a fully functional keypad and mirrors the display. This page is WebSocket based and there is no polling or browser refresh needed.

  There are 4 buttons:
  - [Clock/Calculator/Exit Menu] toggles the device mode or exits the menu mode
  - [Menu] enters the menu mode
  - [Registers] shows/hides all the stack and memory registers with all the digits. The X register holds the current result.
  - [Back] back to homepage
- **[Configuration]** provides full access to the configuration of the calculator.
- **[Status]** displays some status information.
- **[Time Sync]** provides synchronization of the calculator time with the browser time.
- **[SSID & Passwords]** change the SSID, the AP password and the firmware update password
- **[Firmware Update]** OTA firmware update

Be aware that the browser connection is not encrypted and the clear text passwords and the SSID of the AP are stored in flash memory and are also visible in the source code. While connected to this AP, you may have no Internet connection. Press [F] + [ENT] again to stop the server and the AP.

## Peripherals module

If you have assembled the peripherals module you can connect it to the calculator with a straight ethernet patch cable. Turn off the calculator while connecting or disconnecting the ethernet cable.

The default communication speed for the BE-220 GPS module is 38400 and 9600 for the older BN-220 module.

## Reset SSID and passwords

You can reset the SSID, the AP password and the firmware update password to the initial values (defined in the source code) by pressing [F] + [←] in menu mode. This only works if using the physical keyboard.

## "Factory" reset

Press and hold the button on the back for about 4 seconds during the startup. If the reset is successful, all decimal places will flash 5 times. No restart is required after the reset.

## OTA firmware update

If enabled in the firmware configuration, the firmware can be updated "over-the-air" using the web interface:

- Open the web interface in your browser as described in the ["Web server"](#web-server) section.
- Press [F] + [±] to enable OTA firmware update for a few minutes. During this time, the net activity LED will blink.
- Go to the firmware update page
- Enter the firmware update password
- Select the firmware file
- Select [Upload]

After the update, the calculator restarts automatically.

## Troubleshooting

If the calculator loses the time, please change the CR2032 battery.

## Table of shortcuts

| Keys | Description | Mode |
| --- | --- | --- |
| [F] + [←] | Switch LED lighting mode, overrides the time constraints (*) | Calculator, Clock |
| [F] + [CLS] | Restore the lighting time constraints | Calculator, Clock |
| [F] + [STO] | Commit temporarily changed settings | Calculator, Clock |
| [F] + [ENT] | Start/stop Wi-Fi access point and web server | Calculator, Clock |
| [F] + [±] | Enable/disable OTA firmware update | Calculator, Clock |
| [F] + [0] – [8] | Change the number of fixed decimals, 0 = floating (*) | Calculator |
| [F] + [9] | Change the input direction and output format (*) | Calculator |
| [F] + [EXP] | Force scientific notation on or off (*) | Calculator |
| [F] + [.] | Start/stop scrolling additional result digits | Calculator |
| [F] + [+] | Increase brightness (*) | Calculator |
| [F] + [-] | Decrease brightness (*) | Calculator |
| [F] + [00] | Trim X register to displayed value | Calculator |
| [F] + [%] | Toggle rounding mode (*) | Calculator |
| [0] - [9],[00],[.] | Switch the clock mode (*) | Clock |
| [F] + [+] | Adjust the time by plus one second | Clock |
| [F] + [-] | Adjust the time by minus one second | Clock |
| [F] + [0] | Display free heap memory and minimum free heap memory | Clock |
| [F] + [00] | Display firmware versions | Clock |
| [F] + [.] | Display board temperature | Clock |
| [F] + [RCL] | Display uptime in format ddddd hh mm | Clock |
| [F] + [CLR] | Reset all settings to default | Menu |
| [F] + [CLS] | Exit menu mode and discard changes | Menu |
| [F] + [←] | Reset SSID and passwords to default | Menu |

*(\*) temporarily, changed settings are not committed*

## List of error codes

| Error Code | Description |
| --- | --- |
| 1 | Overflow |
| 2 | Divide by zero |
| 3 | Domain error / Invalid input |
| 4 | Out of memory |
| 5 | Indefinite result |
| 6 | Invalid range |
| 7 | No result |
| 8 | Unknown operation |
| 9 | Unknown error |

## List of operations

| Operation | Description |
| --- | --- |
| EXP | Enter exponent |
| clx | Clear X register |
| ← | Clear last entered digit / clear X register if not in input mode |
| CLS | Clear stack and lastX |
| ↑ | Shift key |
| F | Function key |
| x^y | Power |
| x² | Square |
| ʸ√x | Root |
| x³ | Cube |
| 1/x | Reciprocal |
| n! | Factorial |
| eˣ | Exponential |
| ln | Natural logarithm |
| e | e |
| mod | Modulo |
| logy | Logarithm base y |
| py,x | Permutations |
| int | Integer portion |
| sin | Sine |
| sin⁻¹ | Arcsine |
| sinh | Hyperbolic sine |
| cos | Cosine |
| cos⁻¹ | Arccosine |
| cosh | Hyperbolic cosine |
| tan | Tangent |
| tan⁻¹ | Arctangent |
| tanh | Hyperbolic tangent |
| log | Logarithm base 10 |
| π | Pi |
| rnd | Pseudorandom number |
| d↔r | Switch between degrees and radians |
| cy,x | Combinations |
| Δ% | Percent difference |
| ± | Change sign |
| √ | Square root |
| % | Percent |
| ÷ | Division |
| x | Multiplication |
| - | Subtraction |
| + | Addition |
| X↔Y | Swap X and Y registers |
| lstx | Load lastX into the X register |
| R↓ | Roll down stack |
| R↑ | Roll up stack |
| CLR | Clear all memory registers |
| STO | Store into memory register |
| RCL | Recall from memory register |

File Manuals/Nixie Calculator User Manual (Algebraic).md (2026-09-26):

# Nixie Calculator User Manual (Algebraic Version)

*September 26, 2026 — Draft - Version 0.14*

## Table of Contents

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

## General information

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

## Power supply

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

## Power on / Power off

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

## The [F] key

The [F] key has several functions:

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

## The [↑] key

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

## Calculator mode

In this mode the device works like a normal calculator (see [List of operations](#list-of-operations)). However, be aware that the arbitrary-precision arithmetic used by the calculator is experimental.

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

## Clock mode

### Entering date and time

In clock modes (0-9) press the [AC] key. A blinking zero indicates that you can enter the date and the time in the YYYYMMDDhhmmss format. The [C] key deletes the last entered digit. Press [=] to confirm or [AC] to abort.

### Clock modes

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

**Clock modes**

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

**Special clock modes**

| Mode | Description |
| --- | --- |
| 10 | timer |
| 11 | stopwatch |

### Timer

In timer mode press the [AC] key. A blinking zero indicates that you can enter the number of days, hours, minutes, and seconds in the format DDhhmmss. The [C] key deletes the last entered digit. Press [=] to confirm or [AC] to abort. Press [=] to start and stop the timer. Press [C] to reset the timer. Blinking LEDs indicate the end of the countdown; there is no sound. The flashing can be stopped by pressing the [AC] key. The accuracy depends on the internal MCU oscillator.

### Stopwatch

In stopwatch mode press the [=] key to start the stopwatch. Press [=] to pause the display while the stopwatch keeps running. Press [C] to reset the stopwatch. The accuracy depends on the internal MCU oscillator.

## Menu mode

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

### Navigation

| Keys | Description |
| --- | --- |
| [M+] | Next setting |
| [M-] | Previous setting |
| [+] | Next value |
| [-] | Previous value |
| [=] | Accept value and move to the next column if any |
| [C] | Restore to previously stored value |
| [AC] | Reset to default value |
| [F] + [MC] | Reset all settings to default |
| [F] + [AC] | Exit menu mode and discard changes |
| [F] | Exit menu mode and commit changes |

### Settings table

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

*(\*) not available for 7-segment LED version*
*(\*\*) only available if WEB_SUPPORT is set to true*

## Reducing the display on-time

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

## Web server

If enabled in the firmware, press [F] + [=] in calculator mode to start an ESP32 access point (AP) and a web server. After starting, the IP address of the server is displayed for 2 seconds and the network activity LED lights up. By default, the IP address is 192.168.4.1. You can now connect with a smartphone or a PC to this AP and open the site (http://192.168.4.1) with a browser.

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

Be aware that the browser connection is not encrypted and the clear text password and the SSID of the AP are stored in flash memory and are also visible in the source code. While connected to this AP, you may have no Internet connection. Press [F] + [=] again to stop the server and the AP.

## Peripherals module

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

## Reset SSID and passwords

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

## "Factory" reset

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

## OTA firmware update

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

After the update, the calculator restarts automatically.

## Troubleshooting

If the calculator loses the time, please change the CR2032 battery.

## Table of shortcuts

| Keys | Description | Mode |
| --- | --- | --- |
| [F] + [C] | Switch LED lighting mode, overrides the time constraints (*) | Calculator, Clock |
| [F] + [AC] | Restore the lighting time constraints | Calculator, Clock |
| [F] + [MS] | Commit temporarily changed settings | Calculator, Clock |
| [F] + [=] | Start/stop Wi-Fi access point and web server | Calculator, Clock |
| [F] + [±] | Enable/disable OTA firmware update | Calculator, Clock |
| [F] + [0] – [8] | Change the number of fixed decimals, 0 = floating (*) | Calculator |
| [F] + [9] | Change the input direction and output format (*) | Calculator |
| [F] + [EXP] | Force scientific notation on or off (*) | Calculator |
| [F] + [.] | Start/stop scrolling additional result digits | Calculator |
| [F] + [+] | Increase brightness (*) | Calculator |
| [F] + [-] | Decrease brightness (*) | Calculator |
| [F] + [00] | Trim X register to displayed value | Calculator |
| [F] + [%] | Toggle rounding mode (*) | Calculator |
| [0] - [9],[00],[.] | Switch the clock mode (*) | Clock |
| [F] + [+] | Adjust the time by plus one second | Clock |
| [F] + [-] | Adjust the time by minus one second | Clock |
| [F] + [0] | Display free heap memory and minimum free heap memory | Clock |
| [F] + [00] | Display firmware versions | Clock |
| [F] + [.] | Display board temperature | Clock |
| [F] + [M-] | Display uptime in format ddddd hh mm | Clock |
| [F] + [MC] | Reset all settings to default | Menu |
| [F] + [AC] | Exit menu mode and discard changes | Menu |
| [F] + [C] | Reset SSID and passwords to default | Menu |

*(\*) temporarily, changed settings are not committed*

## List of error codes

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

## List of operations

| Operation | Description |
| --- | --- |
| EXP | Enter exponent |
| C | Clear last entered digit / clear display if not in input mode |
| AC | All clear |
| ↑ | Shift key |
| F | Function key |
| x^y | Power |
| x² | Square |
| ʸ√x | Root |
| x³ | Cube |
| 1/x | Reciprocal |
| n! | Factorial |
| eˣ | Exponential |
| ln | Natural logarithm |
| e | e |
| mod | Modulo |
| logy | Logarithm base y |
| py,x | Permutations |
| int | Integer portion |
| sin | Sine |
| sin⁻¹ | Arcsine |
| sinh | Hyperbolic sine |
| cos | Cosine |
| cos⁻¹ | Arccosine |
| cosh | Hyperbolic cosine |
| tan | Tangent |
| tan⁻¹ | Arctangent |
| tanh | Hyperbolic tangent |
| log | Logarithm base 10 |
| π | Pi |
| rnd | Pseudorandom number |
| d↔r | Switch between degrees and radians |
| cy,x | Combinations |
| Δ% | Percent difference |
| ± | Change sign |
| √ | Square root |
| % | Percent |
| ÷ | Division |
| x | Multiplication |
| - | Subtraction |
| + | Addition |
| MC | Clear memory |
| MR | Read memory |
| MS | Store memory |
| M+ | Add to memory |
| M- | Subtract from memory |

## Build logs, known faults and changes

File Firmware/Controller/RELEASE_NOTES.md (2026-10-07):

## Nixie calculator controller firmware
### Version: 0.11.3
Status:    Beta<br/>
Date:      October 7, 2026<br/>
ESP-IDF:   v5.5.5<br/>
Arduino:   v3.3.12<br>
Free Heap: 244000
#### Changes
- Added direct value input in menu mode
- Some minor changes
#### Fixes
- Some minor fixes
---
### Version: 0.11.2
Status:    Beta<br/>
Date:      September 26, 2026<br/>
ESP-IDF:   v5.5.5<br/>
Arduino:   v3.3.12<br>
Free Heap: 245000
#### Changes
- Added a new clock mode that also displays hundredths of a second
- Added new settings for LED lighting brightness
---
### Version: 0.11.1
Status:    Beta<br/>
Date:      September 20, 2026<br/>
ESP-IDF:   v5.5.5<br/>
Arduino:   v3.3.12<br>
Free Heap: 245000
#### Changes
- M7219 driver now uses SPI
- Added time effects (transitions) to 7-segment LED display
---
### Version: 0.11.0
Status:    Beta<br/>
Date:      September 17, 2026<br/>
ESP-IDF:   v5.5.5<br/>
Arduino:   v3.3.11<br>
Free Heap: 245000
#### Changes
- Added a simple calculator self-test suite (not included in the build by default)
#### Fixes
- Fixed endless recursion in ratpowi32
- Fixed missing negative limit check for trigonometric operations
---
### Version: 0.10.0
Status:    Beta<br/>
Date:      September 15, 2026<br/>
ESP-IDF:   v5.5.5<br/>
Arduino:   v3.3.11<br>
Free Heap: 245000
#### Comments
Needs keyboard firmware 0.10.0 or later
#### Changes
- Keyboard communication now takes place entirely via I2C and uses the KINT line to signal data availability, as originally intended.
- Added some digit transition effects for the time display.
---
### Version: 0.9.9
Status:    Beta<br/>
Date:      September 15, 2026<br/>
ESP-IDF:   v5.5.5<br/>
Arduino:   v3.3.11<br>
Free Heap: 246000
#### Changes
- Added offstarttime and offstoptime settings to define a time window where the display should remain switched off.
- Added offdays setting to define the days of the week on which the display should remain switched off.
- Added digittransition setting, currently just a placeholder, not yet implemented
---
### Version: 0.9.8
Status:    Beta<br/>
Date:      September 13, 2026<br/>
ESP-IDF:   v5.5.5<br/>
Arduino:   v3.3.11<br>
Free Heap: 247000
#### Changes
- Moved from bit banging to SPI for faster shift register transfer
---
### Version: 0.9.7
Status:    Beta<br/>
Date:      September 10, 2026<br/>
ESP-IDF:   v5.5.5<br/>
Arduino:   v3.3.11<br>
Free Heap: 247000
#### Changes
- Added information about heap fragmentation to the status page
- Changes made to reduce heap fragmentation, as the firmware should support continuous operation
---
### Version: 0.9.6
Status:    Beta<br/>
Date:      September 8, 2026<br/>
ESP-IDF:   v5.5.5<br/>
Arduino:   v3.3.11<br>
Free Heap: 247000
#### Changes
- Added rounding mode option (5/4 or cut)
- Enhanced look & feel of the web interface
---
### Version: 0.9.5
Status:    Beta<br/>
Date:      September 6, 2026<br/>
ESP-IDF:   v5.5.5<br/>
Arduino:   v3.3.11<br>
Free Heap: 247000
#### Changes
- Added more lighting effects
---
### Version: 0.9.4
Status:    Beta<br/>
Date:      September 3, 2026<br/>
ESP-IDF:   v5.5.5<br/>
Arduino:   v3.3.11<br>
Free Heap: 248000
#### Changes
- The SSID can now be changed using the web interface
---
### Version: 0.9.3
Status:    Beta<br/>
Date:      September 3, 2026<br/>
ESP-IDF:   v5.5.5<br/>
Arduino:   v3.3.11<br>
Free Heap: 252000
#### Comments
LED flickering was fixed by twisting the GND wire with the CTL wire (LED cable) and the GND wire with the BLANK wire (DRIVER cable)
#### Changes
- Re-enabled nixie dimming for IN-12A and B versions
---
### Version: 0.9.2
Status:    Beta<br/>
Date:      September 2, 2026<br/>
ESP-IDF:   v5.5.5<br/>
Arduino:   v3.3.11<br>
Free Heap: 252000
#### Comments
Erase flash before applying this version
#### Changes
- Added OTA firmware update to the web interface
---
### Version: 0.9.1
Status:    Beta<br/>
Date:      August 30, 2026<br/>
ESP-IDF:   v5.5.5<br/>
Arduino:   v3.3.11<br>
Free Heap: 248500
#### Changes
- Replaced std::bind with lambdas
#### Fixes
- Fixed busy calc animations not displaying on calculator page
---
### Version: 0.9.0
Status:    Beta<br/>
Date:      August 29, 2026<br/>
ESP-IDF:   v5.5.5<br/>
Arduino:   v3.3.11<br>
Free Heap: 248500
#### Comments
There is currently nothing else on the "roadmap"
#### Changes
- Added Wi-Fi access point password change page
- Added a "reset password to default" shortcut in menu mode (the shortcut is restricted to the physical keyboard)
- Added page to sync the calculator time with the browser time
- The shortcut [F]+[ENT] / [F]+[=] to start/stop the AP now also works in clock mode
- The shortcut [F]+[STO] / [F]+[MS] now commits all the temporarely changed settings
- Show heap memory shorcut changed to [F]+[0]
- Added a factory reset option by pressing the button at the back for 3 seconds during startup
- Added a new setting to correct the temperature provided by the external sensor
- Added a new setting to correct for potential time drift of the RTC chip.
---
### Version: 0.3.8
Status:    Beta<br/>
Date:      August 27, 2026<br/>
ESP-IDF:   v5.5.5<br/>
Arduino:   v3.3.11<br>
Free Heap: 248500
#### Fixes
- Fixed the status page always showing temperatures in degrees Celsius
- Fixed the calculator display always showing the board temperature in degrees Celsius
- Fixed empty registers on the calculator page after leaving and returning to it
- Fixed stale LED lighting when entering menu mode via the web interface
- Fixed some typos in the comments
---
### Version: 0.3.7
Status:    Beta<br/>
Date:      August 26, 2026<br/>
ESP-IDF:   v5.5.5<br/>
Arduino:   v3.3.11<br>
Free Heap: 248500
#### Changes
- Added new setting "trigcolorchange" that triggers a color change event for RGB random modes in clock mode
- Added new settings "dimbrightness", "dimstarttime" and "dimduration" for time driven brightness change
---
### Version: 0.3.6
Status:    Beta<br/>
Date:      August 26, 2026<br/>
ESP-IDF:   v5.5.5<br/>
Arduino:   v3.3.11<br>
Free Heap: 249000
#### Changes
- Added percentage of "High Voltage On Time" in the status page
#### Fixes
- Timezone rules are now reloaded after a configuration change
---
### Version: 0.3.5
Status:    Beta<br/>
Date:      August 25, 2026<br/>
ESP-IDF:   v5.5.5<br/>
Arduino:   v3.3.11<br>
Free Heap: 249000
#### Changes
- Removed external dependencies by replacing libraries with native drivers and additional code
---
### Version: 0.3.4
Status:    Beta<br/>
Date:      August 15, 2026<br/>
ESP-IDF:   v5.5.5<br/>
Arduino:   v3.3.11<br>
Free Heap: 246000
#### Changes
- Disabled nixie dimming for IN-12A/B display versions due to LED flickering
- Digits on the virtual display are now more visible
---
### Version: 0.3.3
Status:    Beta<br/>
Date:      August 15, 2026<br/>
ESP-IDF:   v5.5.5<br/>
Arduino:   v3.3.11<br>
Free Heap: 246000
#### Changes
- Added "High Voltage On Time" to the status page
- Removed "Calculator Time" from the status page
- For the LED 7-seg version, the virtual display now renders the digits as 7-segment displays
#### Known issues
- PWM nixie dimming is causing LED flickering in the IN-12A/B display versions. Next version will disable PWM dimming for these display types. 
---
### Version: 0.3.2
Status:    Beta<br/>
Date:      August 12, 2026<br/>
ESP-IDF:   v5.5.5<br/>
Arduino:   v3.3.11<br>
Free Heap: 246000
#### Changes
- Added PWM nixie dimming. Setting the brightness to 15 disables PWM
---
### Version: 0.3.1
Status:    Beta<br/>
Date:      August 11, 2026<br/>
ESP-IDF:   v5.5.5<br/>
Arduino:   v3.3.11<br>
Free Heap: 246000
#### Changes
- Added "Calculator" page for device mirroring
- Removed the "Registers" page
- Enhanced performance when showing registers
- Added "apautostart" setting. If set to on, the WiFi access point will be enabled at startup
---
### Version: 0.2.2
Status:    Beta<br/>
Date:      August 8, 2026<br/>
ESP-IDF:   v5.5.5<br/>
Arduino:   v3.3.11<br>
Free Heap: 246560
#### Changes
- Added status web page
- Changed display format for dual time clock mode
#### Fixes
- more understandable names for the rgb mode enums
---
### Version: 0.2.1
Status:    Beta<br/>
Date:      August 8, 2026<br/>
ESP-IDF:   v5.5.5<br/>
Arduino:   v3.3.11<br>
Free Heap: 246608
#### Fixes
- Fixed crash when stopping the web server
---
### Version: 0.2.0
Status:    Beta<br/>
Date:      August 6, 2026<br/>
ESP-IDF:   v5.5.5<br/>
Arduino:   v3.3.11<br>
Free Heap: 246588
#### Changes
- Added configuration web page
#### Fixes
- Fixed typo in Settings.hpp
---
### Version: 0.1.11
Status:    Beta<br/>
Date:      August 6, 2026<br/>
ESP-IDF:   v5.5.5<br/>
Arduino:   v3.3.11<br>
Free Heap: 246628
#### Comments
- Last AI-free version
#### Changes
- CALC_TYPE definition in Config.h has been replaced with RPN_MODE
- WEBSOCKET_SUPPORT definition in Config.h has been replaced with WEB_SUPPORT
#### Fixes
- Fixed duplicate settings name
---
### Version: 0.1.10
Status:    Beta<br/>
Date:      July 27, 2026<br/>
ESP-IDF:   v5.5.5<br/>
Arduino:   v3.3.11<br>
Free Heap: 246628
#### Changes
- Added new setting for blinking behavior during time, timer and menu value input
---
### Version: 0.1.9
Status:    Beta<br/>
Date:      July 26, 2026<br/>
ESP-IDF:   v5.5.4<br/>
Arduino:   v3.3.10<br>
Free Heap: 245428
#### Changes
- Added new setting for the calculator input direction. With this setting you can define
  if the input direction is from right to left, left to right or left to right
  with leading zeros. This setting also affects the output alignment.
- Added shortcut [F]+[9] in calculator mode to temporarily change the input direction
- [F] + [STO] (RPN) / [F] + [MS] (ALG) in calculator mode now also stores the input direction
---
### Version: 0.1.8
Status:    Beta<br/>
Date:      July 20, 2026<br/>
ESP-IDF:   v5.5.4<br/>
Arduino:   v3.3.10<br>
Free Heap: 245408
#### Changes
- Added shortcut [F]+[.] in clock mode to display the board temperature
---
### Version: 0.1.7
Status:    Beta<br/>
Date:      July 19, 2026<br/>
ESP-IDF:   v5.5.4<br/>
Arduino:   v3.3.10<br>
Free Heap: 245408
#### Changes
- Added board temperature monitoring
---
### Version: 0.1.6
Status:    Beta<br/>
Date:      April 25, 2026<br/>
ESP-IDF:   v5.5.4<br/>
Arduino:   v3.3.8<br>
Free Heap: 245888
#### Changes
- Added dual clock mode
- Added new settings for the second timezone
- Added new setting for the second timezone color
- Added new setting for the time separator mode
---
### Version: 0.1.5
Status:    Beta<br/>
Date:      April 13, 2026<br/>
ESP-IDF:   v5.5.4<br/>
Arduino:   v3.3.8<br>
Free Heap: 246968
#### Changes
- Added shortcut to display uptime
- Added shortcut to trim the X register to the displayed value
- Changed some existing shortcuts (see Table of Shortcuts in the manual)
---
### Version: 0.1.4
Status:    Beta<br/>
Date:      February 3, 2026<br/>
ESP-IDF:   v5.5.2<br/>
Arduino:   v3.3.6<br>
Free Heap: 248092
#### Fixes
- fixed an issue introduced with a recent change in the original ratpak that could lead to incorrect results for lograt 
---
### Version: 0.1.3
Status:    Beta<br/>
Date:      January 24, 2026<br/>
ESP-IDF:   v5.5.2<br/>
Arduino:   v3.3.6<br>
Free Heap: 246564
#### Changes
- added yyddmm date format
---
### Version: 0.1.2
Status:  Beta<br/>
Date:    December 26, 2025<br/>
ESP-IDF: v5.5.1<br/>
Arduino: v3.3.3
#### Changes
- added a fix for the √(2.25) - 1.5 rounding issue that was recently merged into the original ratpak code 
- removed my fix for this issue 
---
### Version: 0.1.1
Status:  Beta<br/>
Date:    August 16, 2025<br/>
ESP-IDF: v5.5.1<br/>
Arduino: v3.3.2
#### Changes
- moved access point definitions for SSID and password to Config.h 
- added [F]+[CLS] (RPN) / [F]+[AC] (ALG) shortcut to leave menu mode without storing the changes
---
### Version: 0.1.0
Status:  Beta<br/>
Date:    August 5, 2025
#### Changes
- added INT operation
- added [F]+[00] shortcut in calculator mode to show firmware versions
---
### Version: 0.0.32
Status:  Alpha<br/>
Date:    July 28, 2025
#### Changes
- Updated to arduino-esp32 v3.3.0 / ESP-IDF v5.5.0
- added support for B-5870 nixie display
---
### Version: 0.0.31
Status:  Alpha<br/>
Date:    July 22, 2025
#### Changes
- added support for IN-12 nixie display
---
### Version: 0.0.30
Status:  Alpha<br/>
Date:    July 9, 2025
#### Changes
- added support for IN-16 nixie display
---
### Version: 0.0.29
Status:  Alpha<br/>
Date:    June 26, 2025
#### Changes
- added support for 7-seg LED display
---
### Version: 0.0.28
Status:  Alpha<br/>
Date:    June 22, 2025
#### Changes
- added support for algebraic mode
---
### Version: 0.0.27
Status:  Alpha<br/>
Date:    June 21, 2025
#### Changes
- preparation for algebraic mode support
---
### Version: 0.0.26
Status:  Alpha<br/>
Date:    June 14, 2025
#### Comments
- first published version of the revised firmware
#### Known issues
- RPN support only
- IN-17 display support only
---

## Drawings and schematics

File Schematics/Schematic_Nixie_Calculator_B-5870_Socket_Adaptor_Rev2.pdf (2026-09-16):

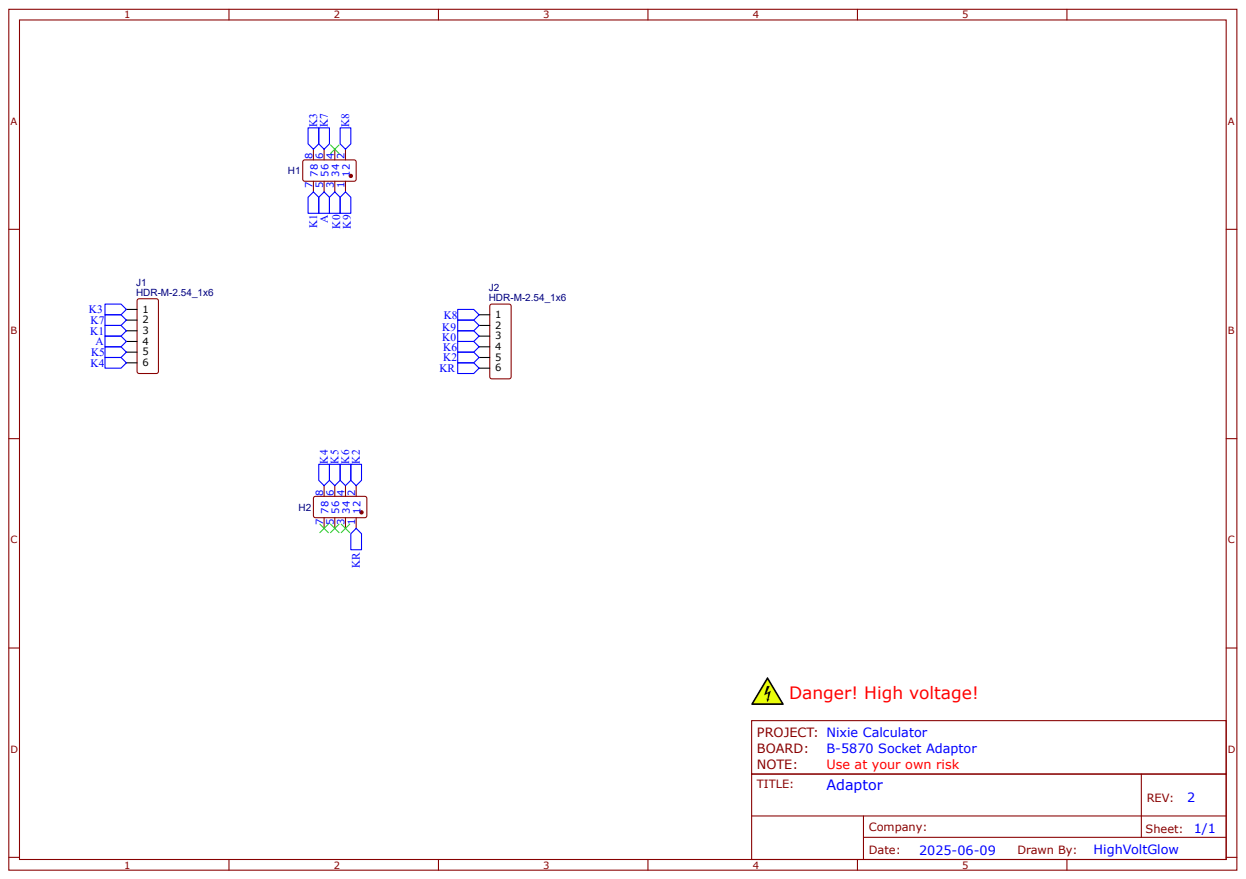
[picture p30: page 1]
TITLE:; Adaptor; REV: 2; Date:; Sheet: 1/1; Drawn By:; Company:; NOTE:; Use at your own risk; HDR-M-2.54_1x6; HighVoltGlow

Danger! High voltage!

PROJECT: Nixie Calculator
BOARD: B-5870 Socket Adaptor

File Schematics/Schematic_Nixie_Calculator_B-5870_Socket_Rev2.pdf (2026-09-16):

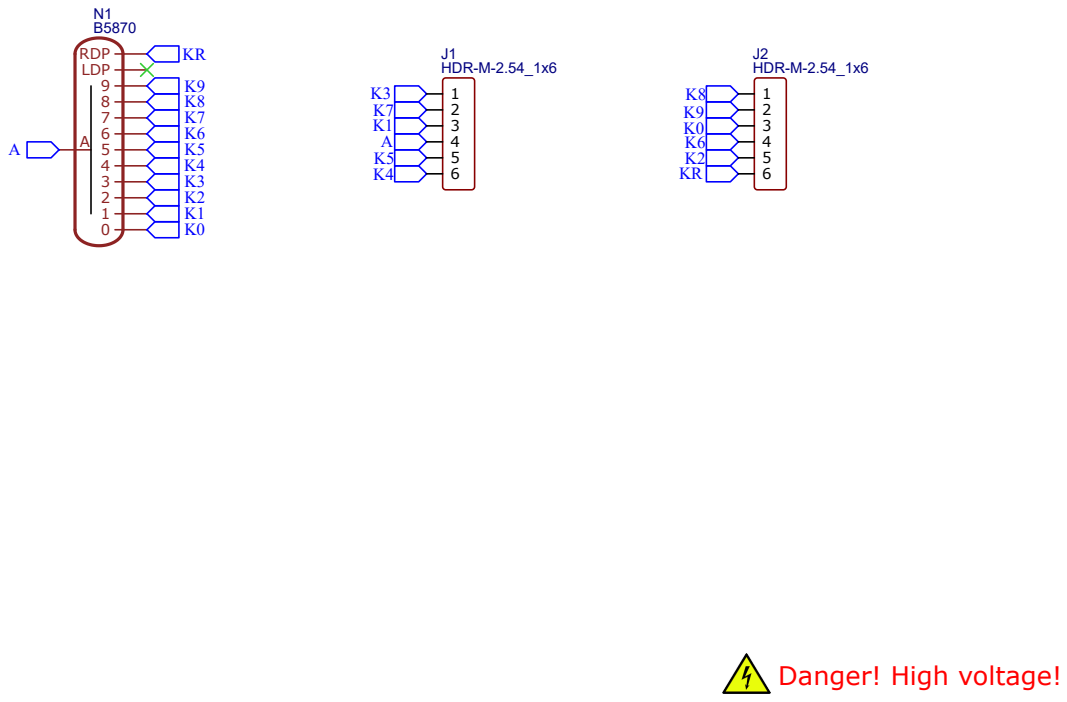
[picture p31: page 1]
TITLE:; Socket; REV: 2; Date:; Sheet: 1/1; Drawn By:; Company:; NOTE:; Use at your own risk; LDP; RDP; HDR-M-2.54_1x6; HighVoltGlow

Danger! High voltage!

PROJECT: Nixie Calculator
BOARD: B-5870 Socket

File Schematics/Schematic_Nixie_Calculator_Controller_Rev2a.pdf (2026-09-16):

## Input Protection (reverse, under and over voltage)

### VIN

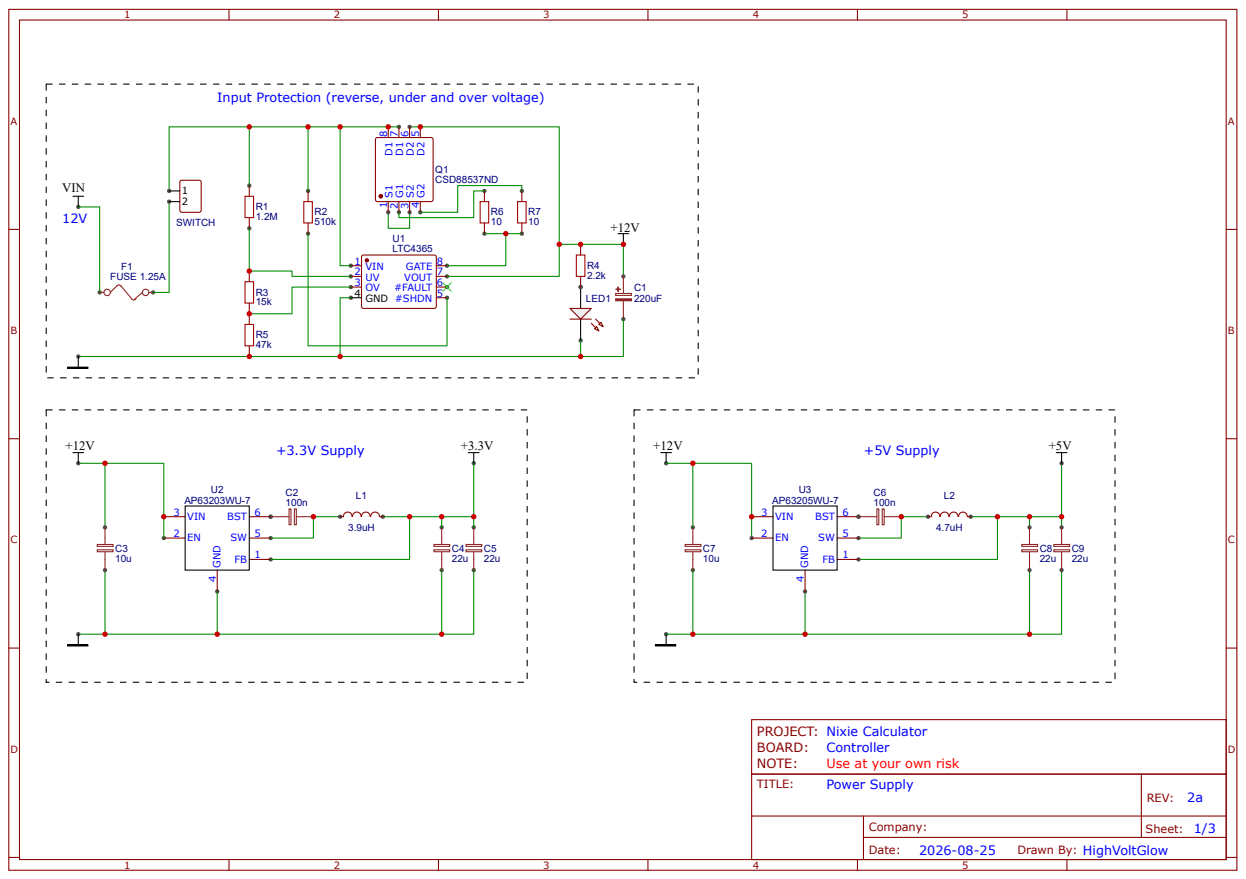
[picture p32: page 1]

+3.3V

## ESP32

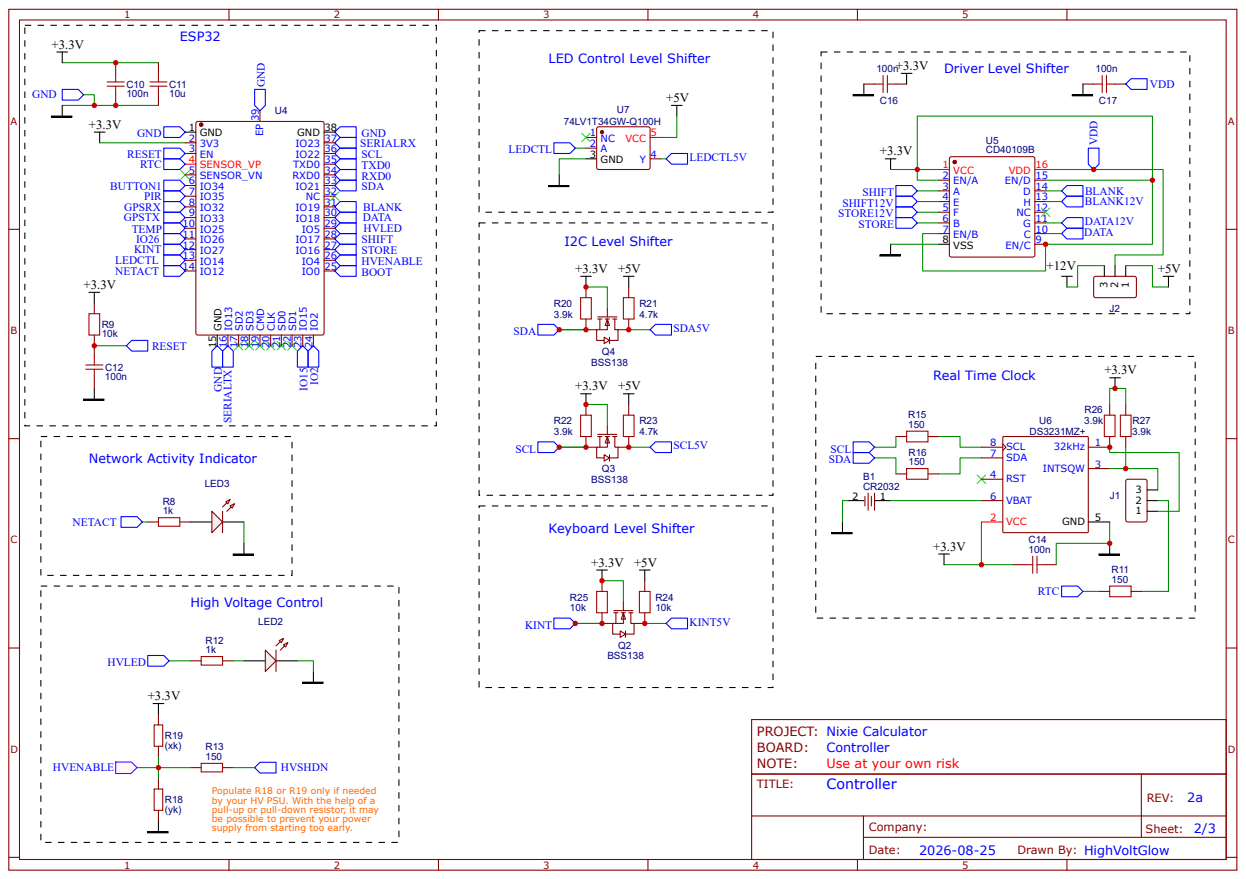
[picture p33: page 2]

LED Control Level Shifter

Populate R18 or R19 only if needed
by your HV PSU. With the help of a
pull-up or pull-down resistor, it may
be possible to prevent your power
supply from starting too early.

+5V

## Extensions

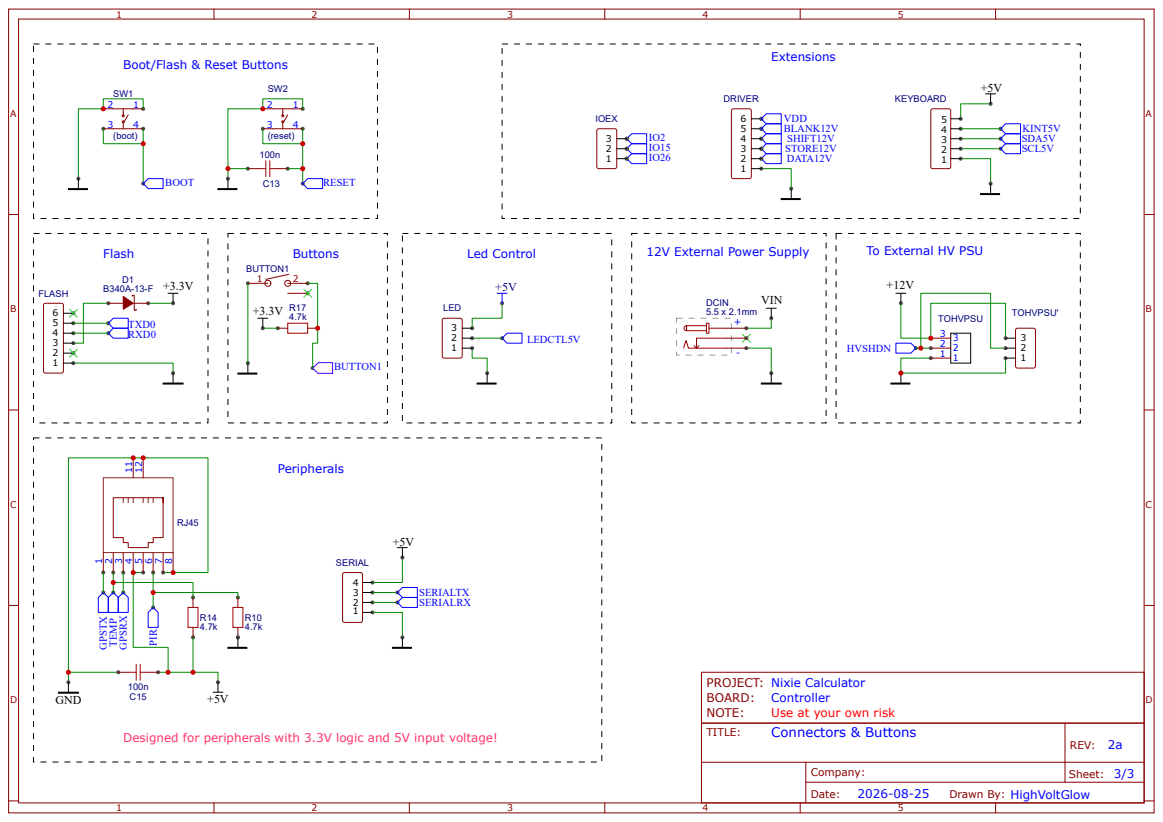
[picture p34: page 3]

Boot/Flash & Reset Buttons

Designed for peripherals with 3.3V logic and 5V input voltage!

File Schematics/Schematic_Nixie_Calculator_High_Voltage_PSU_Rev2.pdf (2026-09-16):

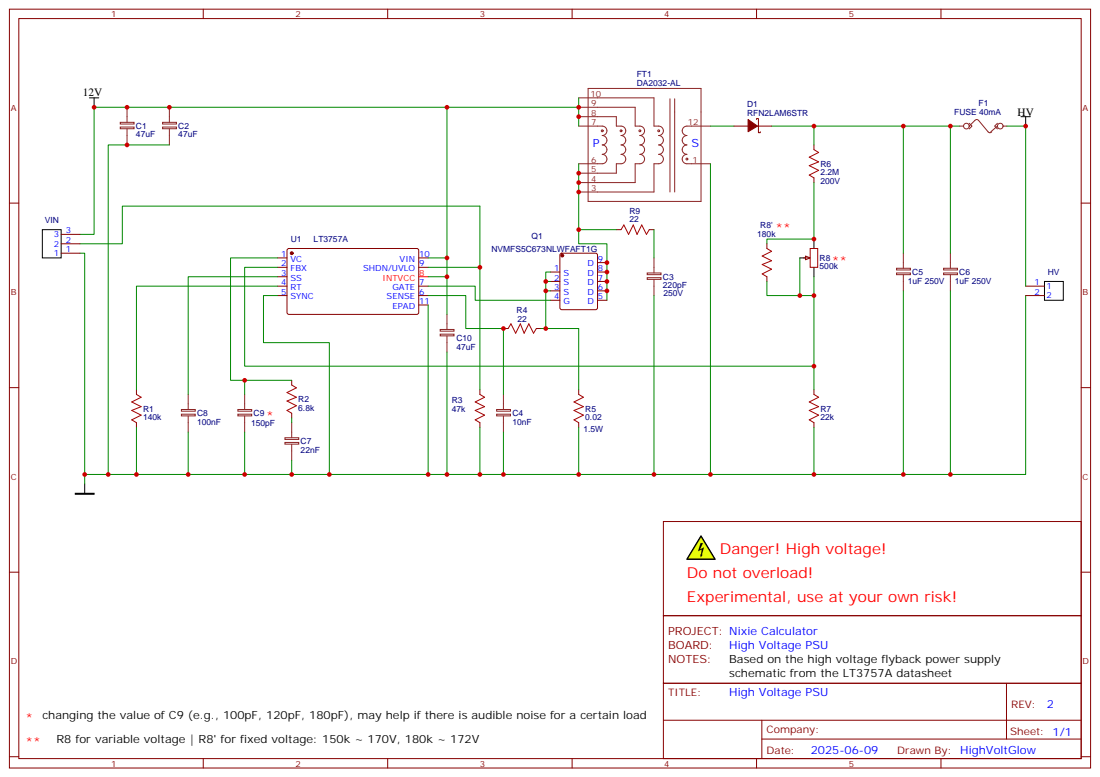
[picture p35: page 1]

Danger! High voltage!
Do not overload!
Experimental, use at your own risk!

High Voltage PSU
Based on the high voltage flyback power supply
schematic from the LT3757A datasheet

changing the value of C9 (e.g., 100pF, 120pF, 180pF), may help if there is audible noise for a certain load
R8 for variable voltage | R8' for fixed voltage: 150k ~ 170V, 180k ~ 172V

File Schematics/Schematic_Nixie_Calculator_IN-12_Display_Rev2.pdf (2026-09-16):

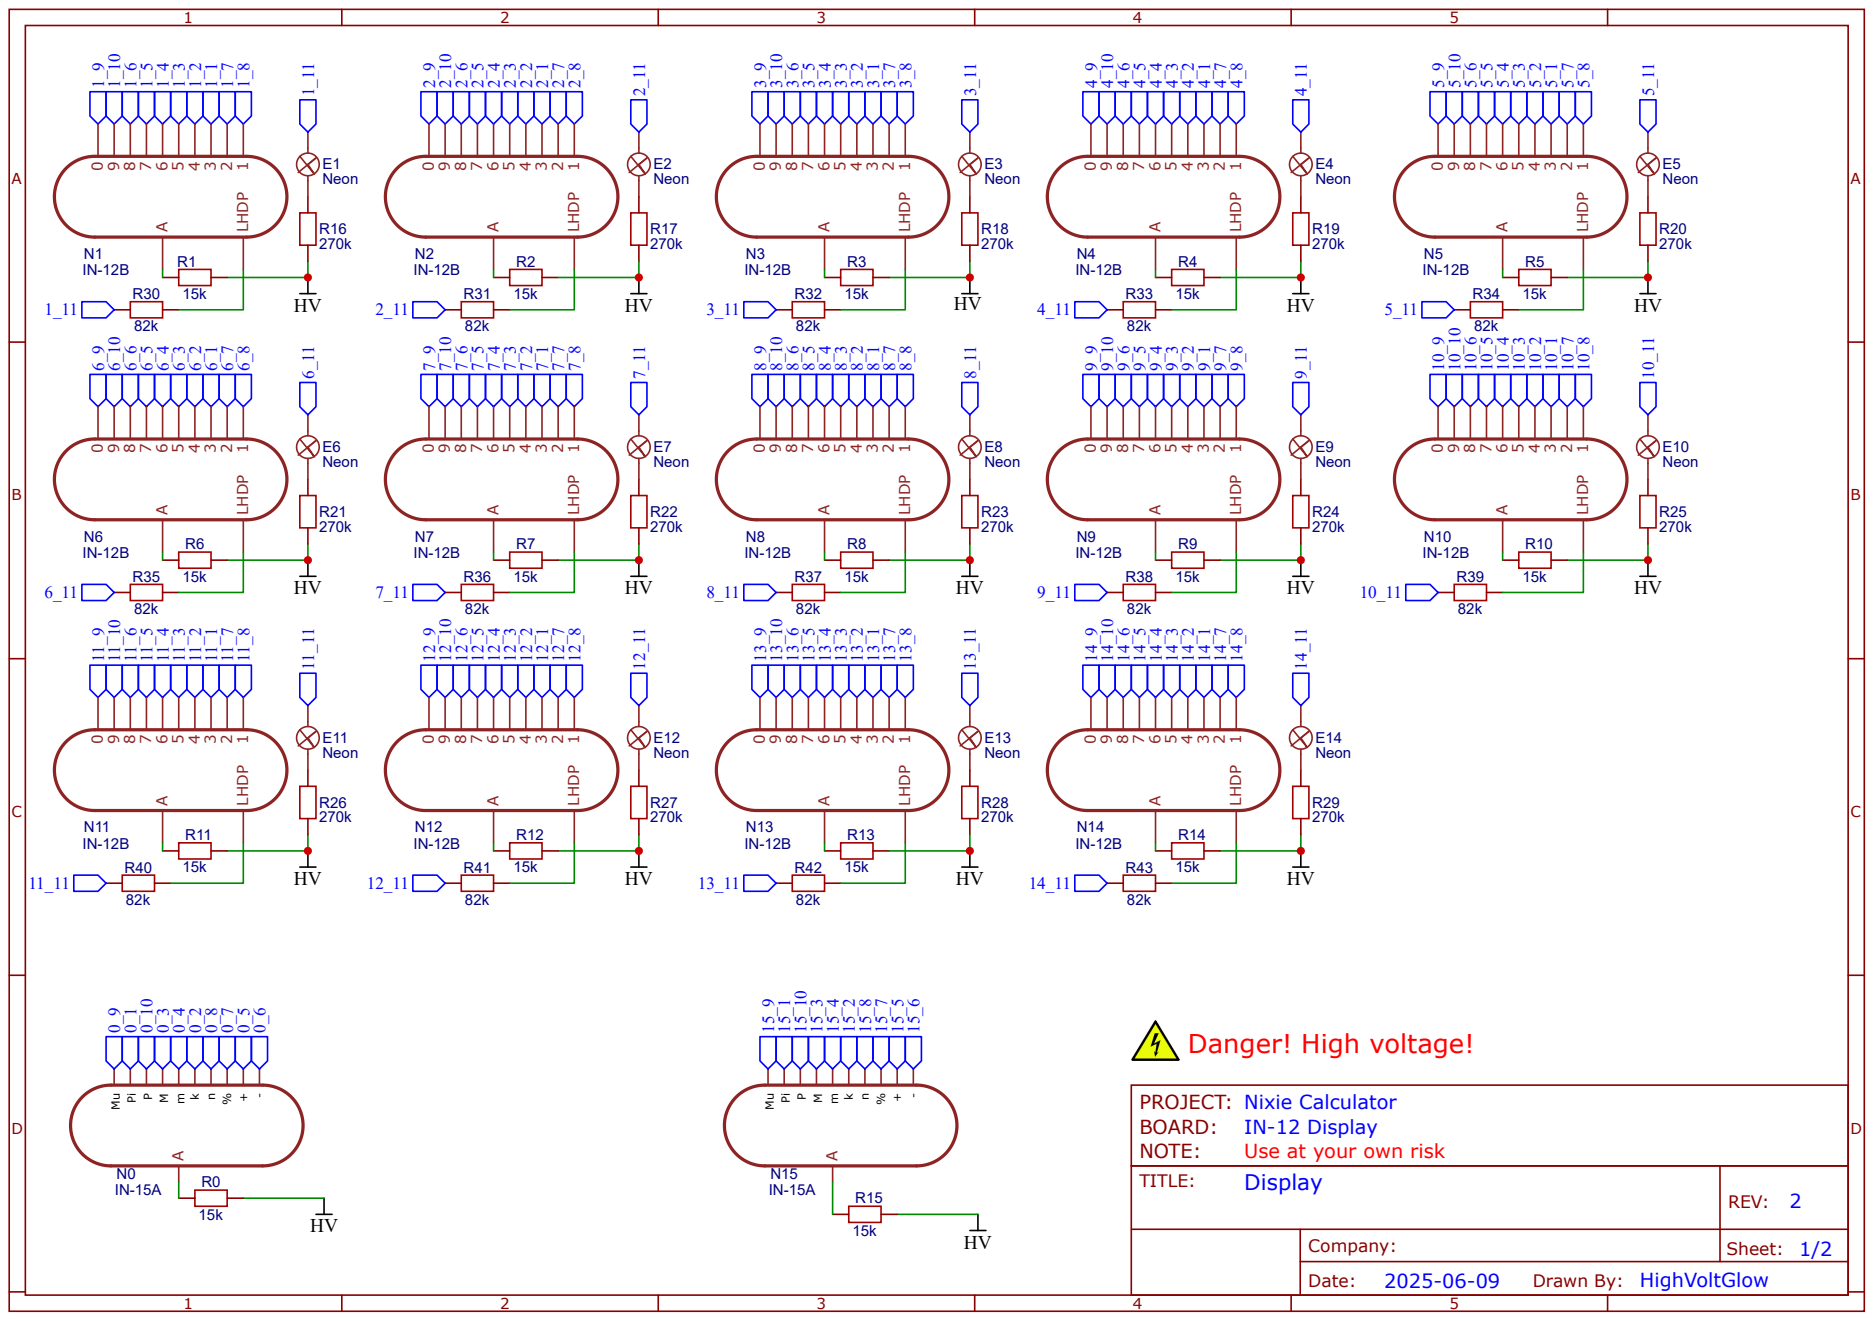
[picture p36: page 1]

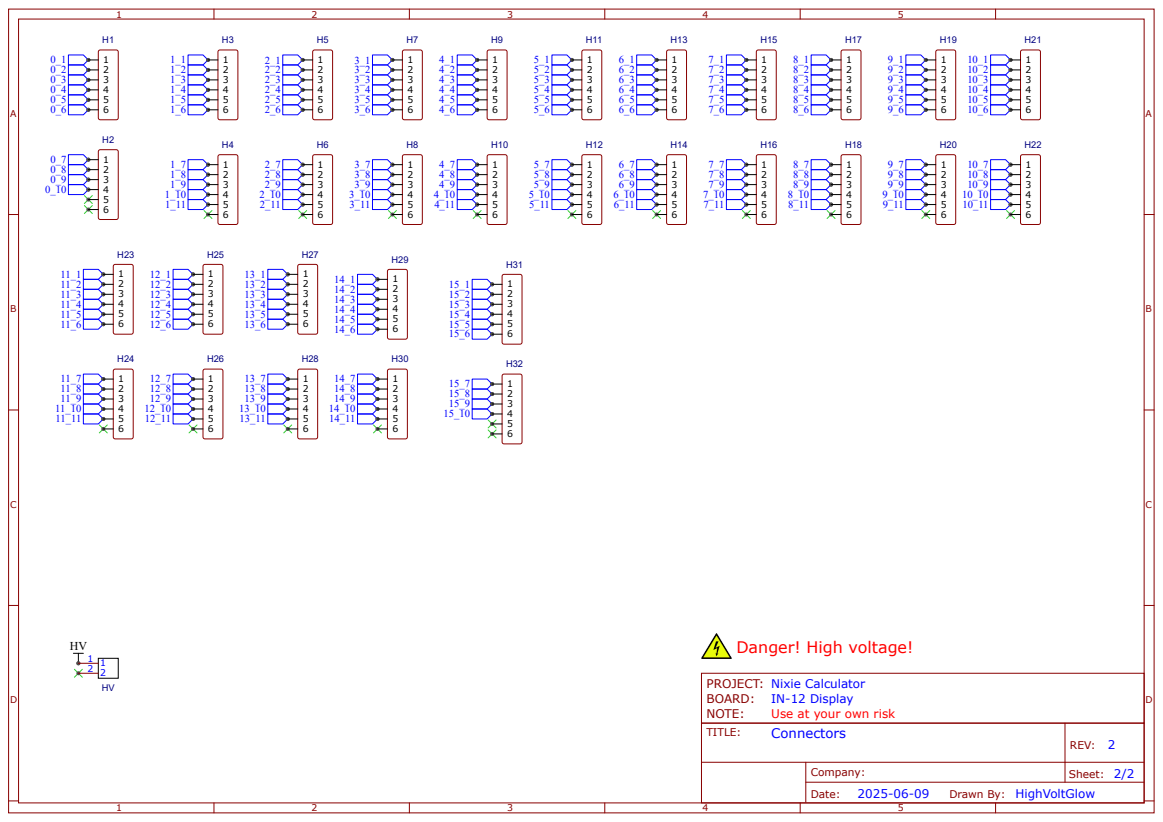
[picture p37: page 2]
TITLE:; Connectors; REV: 2; Date:; Sheet: 2/2; Drawn By:; Company:; NOTE:; Use at your own risk; HighVoltGlow

Danger! High voltage!

PROJECT: Nixie Calculator
BOARD: IN-12 Display

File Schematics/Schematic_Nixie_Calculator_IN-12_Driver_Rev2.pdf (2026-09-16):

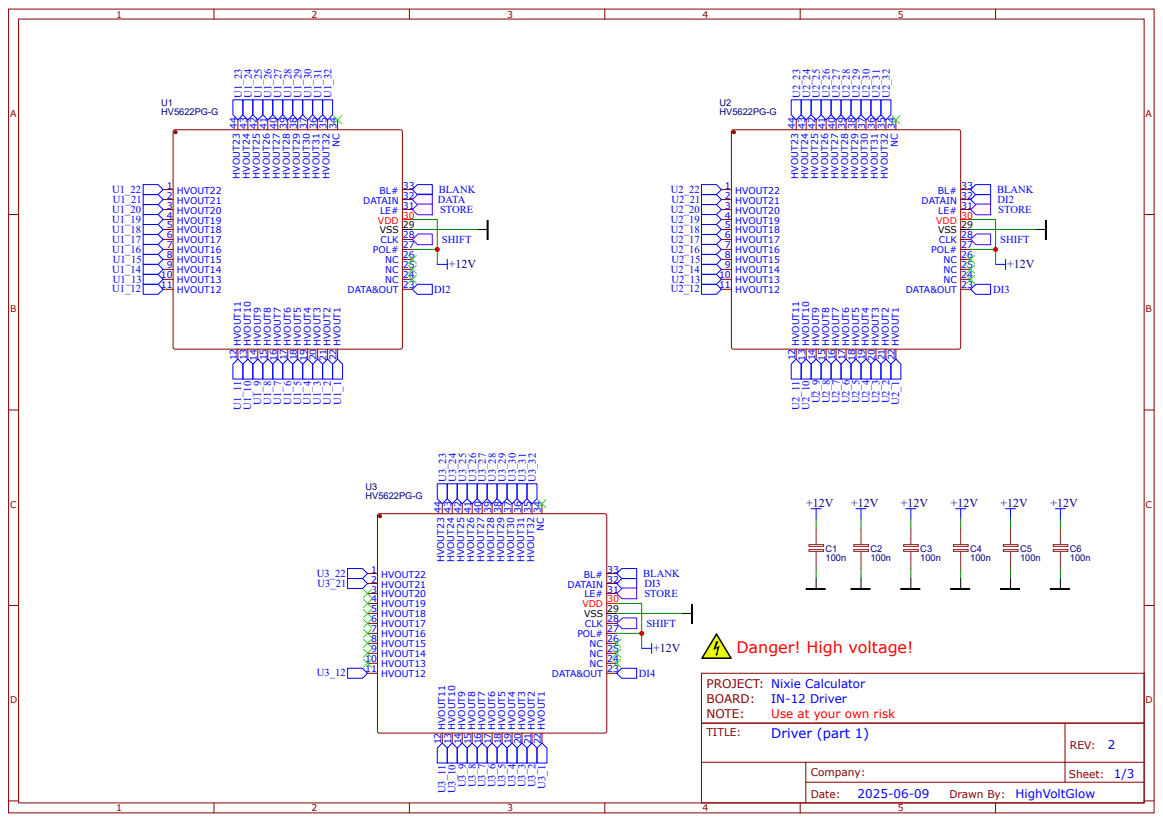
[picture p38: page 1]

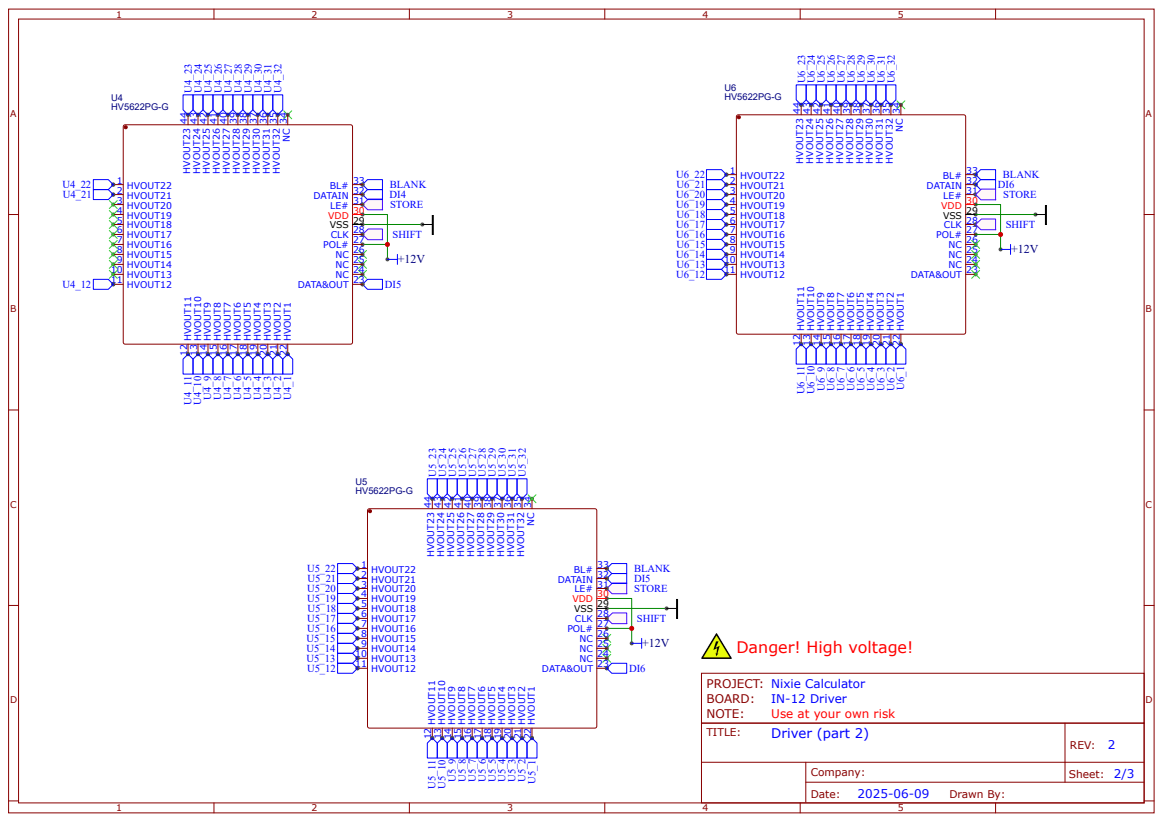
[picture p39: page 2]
TITLE:; Driver (part 2); REV: 2; Sheet: 2/3; Company:; NOTE:; Use at your own risk; BLANK; STORE; SHIFT; HVOUT22; HVOUT21; HVOUT20; HVOUT19; HVOUT18; HVOUT17; HVOUT16; HVOUT15; HVOUT14; HVOUT13; HVOUT12; HVOUT11; HVOUT10; HVOUT9; HVOUT8; HVOUT7; HVOUT6; HVOUT5; HVOUT4; HVOUT3; HVOUT2; HVOUT1; DATA&OUT; POL#; CLK; VSS; VDD; 31 DATAIN; NC 34 HVOUT32; 35 HVOUT31; 36 HVOUT30; 37 HVOUT29; 38 HVOUT28; 39 HVOUT27; 40 HVOUT26; 41 HVOUT25; 42 HVOUT24; 43 HVOUT23; Danger! High voltage!

PROJECT: Nixie Calculator
BOARD: IN-12 Driver

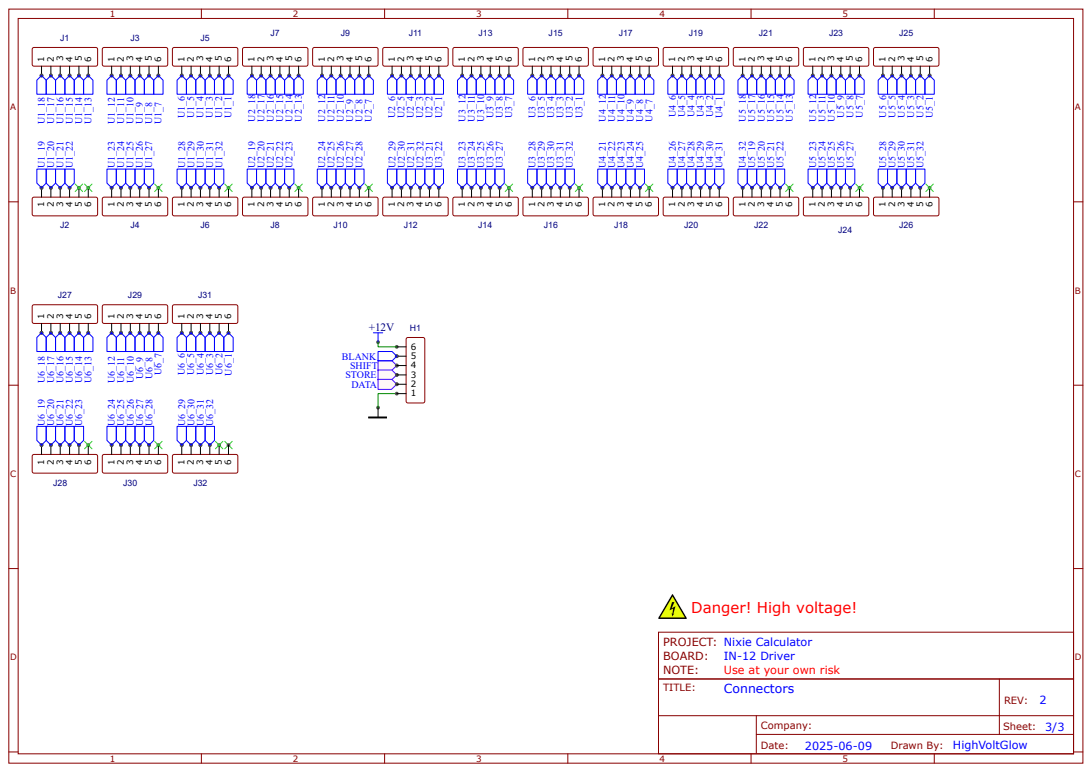
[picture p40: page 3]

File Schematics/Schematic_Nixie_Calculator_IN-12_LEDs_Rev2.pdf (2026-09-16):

A | A

1

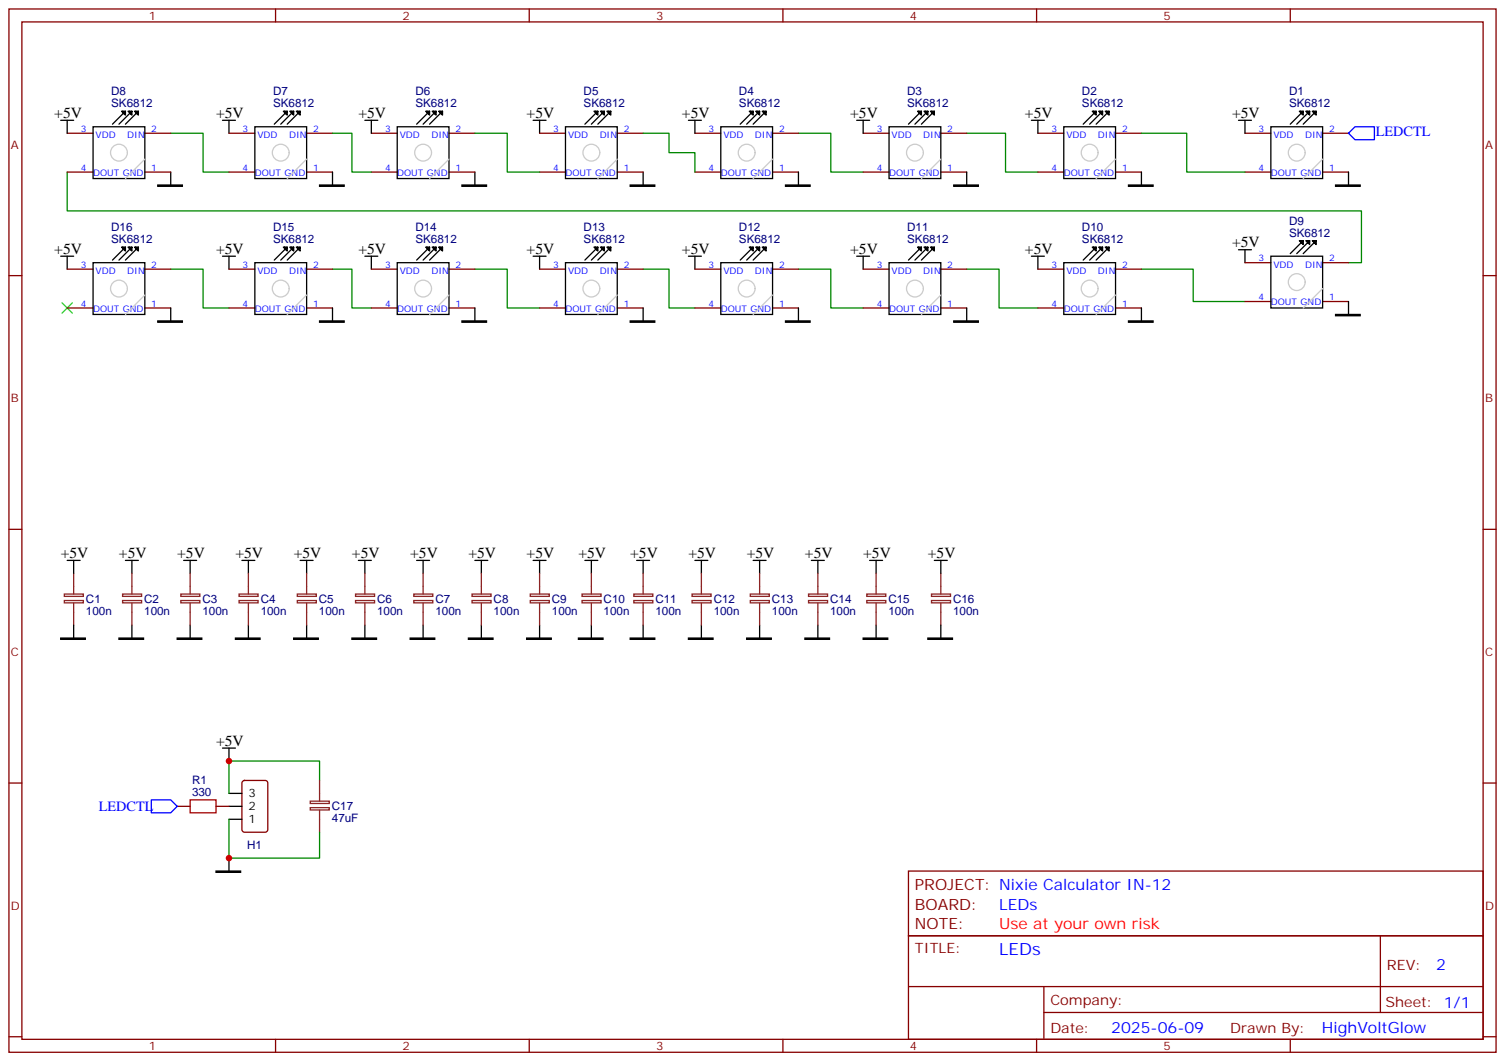
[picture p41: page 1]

PROJECT: Nixie Calculator IN-12
BOARD: LEDs

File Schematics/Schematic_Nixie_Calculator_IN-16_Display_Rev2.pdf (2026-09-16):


TITLE:; Connectors; REV: 2; Date:; Sheet: 2/2; Drawn By:; Company:; NOTE:; Use at your own risk; HVPSU1 1; HighVoltGlow

Danger! High voltage!

PROJECT: Nixie Calculator
BOARD: IN-16 Display



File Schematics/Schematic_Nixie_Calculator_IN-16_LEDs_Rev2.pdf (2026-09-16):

A | A

1


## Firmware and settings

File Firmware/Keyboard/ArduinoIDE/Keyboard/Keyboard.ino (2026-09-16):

// Nixie Calculator Keyboard Firmware

// Copyright (C) 2020-2026 highvoltglow
// Licensed under the MIT License

// Dependencies: https://github.com/chris--a/keypad

// the keyboard receives commands from the controller using I2C
// key events are queued locally and sent to the controller on I2C request
// the KINT pin signals whether a event is queued

// commands:
// CMD_RESET                      -> resets the keyboard
// CMD_GETVERSION                 -> prepares for version request
// CMD_SETHOLDTIME                -> sets the time (ms) after a pressed key changes to hold state
// CMD_SETDEBOUNCETIME            -> sets the debounce time (ms), modify only if you get more events as expected
// CMD_SETAUTOREPEATINTERVAL      -> sets the time (ms) between autorepeat events if a key is hold
// CMD_SETFASTAUTOREPEATINTERVAL  -> sets the time (ms) between autorepeat events after the fast autorepeat delay
// CMD_SETFASTAUTOREPEATDELAY     -> sets the number of autorepeat events before changing to the fast autorepeat interval

// default event sequence:
// key pressed  -> "pressed" event
// key released -> "released" event, "idle" event

// event sequence with default values and hold:
// ------------------------------------------------------------------------------------------------
// | holdTime = 1000, autoRepeatInterval = 0, fastAutoRepeatInterval = 0, fastAutoRepeatDelay = 0 |
// ------------------------------------------------------------------------------------------------
// key pressed  -> "pressed" event
// time +1000   -> "hold" event
// ...
// key released -> "released" event, "idle" event

// event sequence example with auto repeat:
// ----------------------------------------------------------------------------------------------------
// | holdTime = 1000, autoRepeatInterval = 500, fastAutoRepeatInterval = 250, fastAutoRepeatDelay = 3 |
// ----------------------------------------------------------------------------------------------------
// key pressed  -> "pressed" event
// time +1000   -> "hold" event, "autorepeat" event
// time +1500   -> "autorepeat" event
// time +2000   -> "autorepeat" event
// time +2250   -> "autorepeat" event (fast)
// time +2500   -> "autorepeat" event (fast)
// ...
// key released -> "released" event, "idle" event

// includes
#include <Arduino.h>
#include <Wire.h>
#include <Keypad.h>

// version information
constexpr uint8_t MAJOR_VERSION = 0;
constexpr uint8_t MINOR_VERSION = 10;
constexpr uint8_t REVISION = 0;
constexpr auto FW_STATUS = "beta";

// Set to false to disable custom serial print
// Set to true to enable custom serial print
#define ENABLE_SERIAL_PRINT false

#if ENABLE_SERIAL_PRINT
#define __serial_begin(...) Serial.begin(__VA_ARGS__);
#define __serial_print(...) Serial.print(__VA_ARGS__)
#define __serial_println(...) Serial.println(__VA_ARGS__)
#define __serial_printf(...) Serial.printf(__VA_ARGS__)
#else
#define __serial_begin(...)
#define __serial_print(...)
#define __serial_println(...)
#define __serial_printf(...)
#endif

// I2C address
constexpr uint8_t I2C_ADDRESS = 2;

// commands
constexpr uint8_t CMDINDENTIFIER = '@';
constexpr uint8_t CMD_RESET = 1;
constexpr uint8_t CMD_GETVERSION = 2;
constexpr uint8_t CMD_SETHOLDTIME = 3;
constexpr uint8_t CMD_SETDEBOUNCETIME = 4;
constexpr uint8_t CMD_SETAUTOREPEATINTERVAL = 5;
constexpr uint8_t CMD_SETFASTAUTOREPEATINTERVAL = 6;
constexpr uint8_t CMD_SETFASTAUTOREPEATDELAY = 7;

// keys arranged in 8 x 5 matrix
constexpr uint8_t ROWS = 8;
constexpr uint8_t COLS = 5;

// data-ready pin
constexpr uint8_t PIN_KINT = 17;

// this is an additional KeyState used
// for generated repeat events
constexpr auto KEYSTATE_AUTOREPEAT = 4;

// size of key event served over I2C
constexpr size_t KEY_INFO_SIZE = 2;

// depth of the pending key event queue
constexpr uint8_t KEY_QUEUE_SIZE = 8;

// used for auto-repeat handling
typedef struct
{
  uint8_t keyCode;
  unsigned long holdTimestamp;
  uint autoRepeatCount;
} HOLD_INFO;

// a single queued key event, served to the controller on I2C request
typedef struct
{
  uint8_t keyCode;
  uint8_t state;
} KEY_EVENT;

// key values
char keys[ROWS][COLS] = {{1, 2, 3, 4, 5},
                         {6, 7, 8, 9, 10},
                         {11, 12, 13, 14, 15},
                         {16, 17, 18, 19, 20},
                         {21, 22, 23, 24, 25},
                         {26, 27, 28, 29, 30},
                         {31, 32, 33, 34, 35},
                         {36, 37, 38, 39, 40}};

// matrix pins
byte rowPins[ROWS] = {16, 15, 14, 13, 7, 6, 5, 4};
byte colPins[COLS] = {12, 11, 10, 9, 8};

// keypad instance
Keypad keypad = Keypad(makeKeymap(keys), rowPins, colPins, ROWS, COLS);

// key hold timestamp array for auto repeat function
HOLD_INFO keyHoldInfo[LIST_MAX];

// pending key event queue, shared between loop() and the I2C request ISR
volatile KEY_EVENT keyQueue[KEY_QUEUE_SIZE];
volatile uint8_t keyQueueHead = 0; // next slot to pop
volatile uint8_t keyQueueTail = 0; // next slot to push
volatile uint8_t keyQueueCount = 0;

volatile uint16_t holdTime = 1000;
volatile uint16_t debounceTime = 10;
volatile uint16_t autoRepeatInterval = 0;
volatile uint16_t fastAutoRepeatInterval = 0;
volatile uint16_t fastAutoRepeatDelay = 0;
volatile int pendingRequest = -1;

// forward declarations
void (*reset)(void) = 0;
void receiveEvent(int count);
void requestEvent();
void onReset();
void onGetVersion();
void onSetHoldTime();
void onSetDebounceTime();
void onSetAutoRepeatInterval();
void onSetFastAutoRepeatInterval();
void onSetFastAutoRepeatDelay();
void queueKeyEvent(uint8_t keyCode, uint8_t state);
void updateDataReadyPin();

void deleteKeyHoldInfo(uint8_t keyCode);
void setKeyHoldInfo(uint8_t keyCode);
void initKeyHoldInfo();
uint16_t readUInt();

void setup()
{
  __serial_begin(9600);

  // queue starts empty
  pinMode(PIN_KINT, OUTPUT);
  digitalWrite(PIN_KINT, LOW);

  // init the hold timestamp table
  initKeyHoldInfo();

  // set default values
  keypad.setHoldTime(holdTime);
  keypad.setDebounceTime(debounceTime);

  // init I2C connection
  Wire.begin(I2C_ADDRESS);
  Wire.onReceive(receiveEvent);
  Wire.onRequest(requestEvent);
}

void loop()
{
  // check for keys
  if (keypad.getKeys())
  {
    for (uint8_t i = 0; i < LIST_MAX; i++)
    {
      if (keypad.key[i].stateChanged)
      {

        // some debug information
        __serial_print("Millis: ");
        __serial_print(millis());
        __serial_print(" ");
        __serial_print("Key: ");
        __serial_print((int)keypad.key[i].kchar);
        __serial_print(" ");
        __serial_print("State: ");
        __serial_println(keypad.key[i].kstate);

        // keypad state changed, queue key and state 
        queueKeyEvent((uint8_t)keypad.key[i].kchar, (uint8_t)keypad.key[i].kstate);
        // set/delete hold timestamp
        if (autoRepeatInterval > 0)
        {
          switch (keypad.key[i].kstate)
          {
          case KeyState::HOLD:
            setKeyHoldInfo((uint8_t)keypad.key[i].kchar);
            break;

          case KeyState::RELEASED:
            deleteKeyHoldInfo((uint8_t)keypad.key[i].kchar);
            break;

          default:
            break;
          }
        }
      }
    }
  }
  // check for auto repeat
  if (autoRepeatInterval > 0)
  {
    unsigned long currentMillis = millis();
    for (uint8_t i = 0; i < LIST_MAX; i++)
    {

      if (keyHoldInfo[i].keyCode != 0)
      {
        bool genEvent = false;
        if ((keyHoldInfo[i].autoRepeatCount < fastAutoRepeatDelay) || (fastAutoRepeatDelay == 0))
        {
          // check if it is time to generate a key repeat event
          if (currentMillis - keyHoldInfo[i].holdTimestamp > autoRepeatInterval)
          {
            genEvent = true;
          }
        }
        else
        {
          // check if it is time to generate a key fast repeat event
          if (fastAutoRepeatInterval > 0)
          {
            if (currentMillis - keyHoldInfo[i].holdTimestamp > fastAutoRepeatInterval)
            {
              genEvent = true;
            }
          }
        }
        if (genEvent)
        {

          __serial_print("Millis: ");
          __serial_print(millis());
          __serial_print(" ");
          __serial_print("Key: ");
          __serial_print(keyHoldInfo[i].keyCode);
          __serial_print(" ");
          __serial_print("State: ");
          __serial_println(KEYSTATE_AUTOREPEAT);

          queueKeyEvent(keyHoldInfo[i].keyCode, KEYSTATE_AUTOREPEAT);
          keyHoldInfo[i].holdTimestamp = currentMillis;
          if (fastAutoRepeatInterval > 0)
          {
            keyHoldInfo[i].autoRepeatCount++;
          }
        }
      }
    }
  }
}

// event handler for I2C commands
void receiveEvent(int count)
{
  while (Wire.available())
  {
    char c = Wire.read();
    if (c == CMDINDENTIFIER)
    {
      int command = Wire.read();
      switch (command)
      {
      case CMD_RESET:
        onReset();
        break;

      case CMD_GETVERSION:
        onGetVersion();
        break;

      case CMD_SETHOLDTIME:
        onSetHoldTime();
        break;

      case CMD_SETDEBOUNCETIME:
        onSetDebounceTime();
        break;

      case CMD_SETAUTOREPEATINTERVAL:
        onSetAutoRepeatInterval();
        break;

      case CMD_SETFASTAUTOREPEATINTERVAL:
        onSetFastAutoRepeatInterval();
        break;

      case CMD_SETFASTAUTOREPEATDELAY:
        onSetFastAutoRepeatDelay();
        break;

      default:
        break;
      }
    }
  }
}

// request handler
void requestEvent()
{
  switch (pendingRequest)
  {
  case CMD_GETVERSION:
    Wire.write(MAJOR_VERSION);
    Wire.write(MINOR_VERSION);
    Wire.write(REVISION);
    pendingRequest = -1;
    break;

  default:
    // no command, just send the oldest key event if any
    if (keyQueueCount > 0)
    {
      Wire.write(keyQueue[keyQueueHead].keyCode);
      Wire.write(keyQueue[keyQueueHead].state);
      keyQueueHead = (keyQueueHead + 1) % KEY_QUEUE_SIZE;
      keyQueueCount--;
      updateDataReadyPin();
    }
    else
    {
      Wire.write((uint8_t)0);
      Wire.write((uint8_t)0);
    }
    break;
  }
}

// push a key event onto the queue
void queueKeyEvent(uint8_t keyCode, uint8_t state)
{
  noInterrupts();
  if (keyQueueCount == KEY_QUEUE_SIZE)
  {
    // drop the oldest event to make room for the newest one
    keyQueueHead = (keyQueueHead + 1) % KEY_QUEUE_SIZE;
    keyQueueCount--;
  }
  keyQueue[keyQueueTail].keyCode = keyCode;
  keyQueue[keyQueueTail].state = state;
  keyQueueTail = (keyQueueTail + 1) % KEY_QUEUE_SIZE;
  keyQueueCount++;
  interrupts();
  updateDataReadyPin();
}

// inform about queue state 
void updateDataReadyPin()
{
  digitalWrite(PIN_KINT, keyQueueCount > 0 ? HIGH : LOW);
}

// reset the keyboard
void onReset()
{
  reset();
}

// prepare to answer version request
void onGetVersion()
{
  pendingRequest = CMD_GETVERSION;
}

// set new hold time value
void onSetHoldTime()
{
  holdTime = readUInt();
  keypad.setHoldTime(holdTime);
}

// set new debounce time value
void onSetDebounceTime()
{
  debounceTime = readUInt();
  keypad.setDebounceTime(debounceTime);
}

// set the key repeat interval
// set to 0 to disable auto repeat
void onSetAutoRepeatInterval()
{
  autoRepeatInterval = readUInt();
  initKeyHoldInfo();
  __serial_println(autoRepeatInterval);
}

// set the key fast repeat interval
// set to 0 to disable fast auto repeat
void onSetFastAutoRepeatInterval()
{
  fastAutoRepeatInterval = readUInt();
}

// sets the delay before changing to fast repeat interval
void onSetFastAutoRepeatDelay()
{
  fastAutoRepeatDelay = readUInt();
}

// delete the hold timestamp for this key
void deleteKeyHoldInfo(uint8_t keyCode)
{
  for (int i = 0; i < LIST_MAX; i++)
  {
    if (keyHoldInfo[i].keyCode == keyCode)
    {
      keyHoldInfo[i].keyCode = 0;
      keyHoldInfo[i].holdTimestamp = 0;
      keyHoldInfo[i].autoRepeatCount = 0;
      break;
    }
  }
}

// set the hold timestamp for this key
void setKeyHoldInfo(uint8_t keyCode)
{
  for (int i = 0; i < LIST_MAX; i++)
  {
    if (keyHoldInfo[i].keyCode == 0)
    {
      keyHoldInfo[i].keyCode = keyCode;
      keyHoldInfo[i].holdTimestamp = millis() + autoRepeatInterval;
      keyHoldInfo[i].autoRepeatCount = 0;
      break;
    }
  }
}

// initialize the key hold timestamp table
void initKeyHoldInfo()
{
  for (int i = 0; i < LIST_MAX; i++)
  {
    keyHoldInfo[i].keyCode = 0;
    keyHoldInfo[i].holdTimestamp = 0;
    keyHoldInfo[i].autoRepeatCount = 0;
  }
}

// read a 2 byte unsigned integer from the wire
uint16_t readUInt()
{
  uint16_t result = 0;
  uint8_t loByte;
  uint8_t hiByte;

  hiByte = Wire.read();
  loByte = Wire.read();

  result = hiByte << 8 | loByte;
  return (result);
}

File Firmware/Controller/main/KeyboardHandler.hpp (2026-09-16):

// KeyboardHandler.hpp

// Copyright (C) 2020-2026 highvoltglow
// Licensed under the MIT License

#pragma once

#include <Arduino.h>
#include <Wire.h>
#include <Config.h>

#if RPN_MODE

// keys scan code                 primary operation
// --------------                 -----------------
constexpr uint8_t KEY_EXP = 1;    // exponent
constexpr uint8_t KEY_BACK = 2;   // backspace
constexpr uint8_t KEY_CLS = 3;    // clear stack
constexpr uint8_t KEY_SHIFT = 4;  // yellow operations
constexpr uint8_t KEY_F = 5;      // function key, blue operations
constexpr uint8_t KEY_POW = 6;    // power
constexpr uint8_t KEY_YROOT = 7;  // y root
constexpr uint8_t KEY_INV = 8;    // invert
constexpr uint8_t KEY_LN = 9;     // natural log
constexpr uint8_t KEY_LOGY = 10;  // log base y
constexpr uint8_t KEY_SIN = 11;   // sine
constexpr uint8_t KEY_COS = 12;   // cosine
constexpr uint8_t KEY_TAN = 13;   // tangent
constexpr uint8_t KEY_LOG = 14;   // log 10
constexpr uint8_t KEY_DEG = 15;   // deg<->rad
constexpr uint8_t KEY_CHS = 16;   // change sign +/-
constexpr uint8_t KEY_7 = 17;     // 7
constexpr uint8_t KEY_4 = 18;     // 4
constexpr uint8_t KEY_1 = 19;     // 1
constexpr uint8_t KEY_0 = 20;     // 0
constexpr uint8_t KEY_SQRT = 21;  // square root
constexpr uint8_t KEY_8 = 22;     // 8
constexpr uint8_t KEY_5 = 23;     // 5
constexpr uint8_t KEY_2 = 24;     // 2
constexpr uint8_t KEY_00 = 25;    // double 0
constexpr uint8_t KEY_PCT = 26;   // percent
constexpr uint8_t KEY_9 = 27;     // 9
constexpr uint8_t KEY_6 = 28;     // 6
constexpr uint8_t KEY_3 = 29;     // 3
constexpr uint8_t KEY_DOT = 30;   // decimal separator
constexpr uint8_t KEY_DIV = 31;   // division
constexpr uint8_t KEY_MUL = 32;   // multiplication
constexpr uint8_t KEY_MINUS = 33; // subtraction
constexpr uint8_t KEY_PLUS = 34;  // addition
constexpr uint8_t KEY_ENTER = 35; // enter
constexpr uint8_t KEY_XY = 36;    // X<->Y
constexpr uint8_t KEY_ROLL = 37;  // roll stack
constexpr uint8_t KEY_CLR = 38;   // clear registers
constexpr uint8_t KEY_STO = 39;   // store register
constexpr uint8_t KEY_RCL = 40;   // recall register

#else

constexpr uint8_t KEY_EXP = 1;     // exponent
constexpr uint8_t KEY_C = 2;       // clear
constexpr uint8_t KEY_AC = 3;      // all clear
constexpr uint8_t KEY_SHIFT = 4;   // yellow operations
constexpr uint8_t KEY_F = 5;       // function key, blue operations
constexpr uint8_t KEY_POW = 6;     // power
constexpr uint8_t KEY_YROOT = 7;   // y root
constexpr uint8_t KEY_INV = 8;     // invert
constexpr uint8_t KEY_LN = 9;      // natural log
constexpr uint8_t KEY_LOGY = 10;   // log base y
constexpr uint8_t KEY_SIN = 11;    // sine
constexpr uint8_t KEY_COS = 12;    // cosine
constexpr uint8_t KEY_TAN = 13;    // tangent
constexpr uint8_t KEY_LOG = 14;    // log 10
constexpr uint8_t KEY_DEG = 15;    // deg<->rad
constexpr uint8_t KEY_CHS = 16;    // change sign +/-
constexpr uint8_t KEY_7 = 17;      // 7
constexpr uint8_t KEY_4 = 18;      // 4
constexpr uint8_t KEY_1 = 19;      // 1
constexpr uint8_t KEY_0 = 20;      // 0
constexpr uint8_t KEY_SQRT = 21;   // square root
constexpr uint8_t KEY_8 = 22;      // 8
constexpr uint8_t KEY_5 = 23;      // 5
constexpr uint8_t KEY_2 = 24;      // 2
constexpr uint8_t KEY_00 = 25;     // double 0
constexpr uint8_t KEY_PCT = 26;    // percent
constexpr uint8_t KEY_9 = 27;      // 9
constexpr uint8_t KEY_6 = 28;      // 6
constexpr uint8_t KEY_3 = 29;      // 3
constexpr uint8_t KEY_DOT = 30;    // decimal separator
constexpr uint8_t KEY_DIV = 31;    // division
constexpr uint8_t KEY_MUL = 32;    // multiplication
constexpr uint8_t KEY_MINUS = 33;  // subtraction
constexpr uint8_t KEY_PLUS = 34;   // addition
constexpr uint8_t KEY_EQUALS = 35; // =
constexpr uint8_t KEY_MC = 36;     // memory clear
constexpr uint8_t KEY_MR = 37;     // memory read
constexpr uint8_t KEY_MS = 38;     // memory store
constexpr uint8_t KEY_MPLUS = 39;  // add to memory
constexpr uint8_t KEY_MMINUS = 40; // subtract from memory

#endif

// size of key info delivered over I2C
constexpr uint8_t KEY_INFO_SIZE = 2;

// keyboard I2C address
constexpr int KEYBOARD_I2C_ADDRESS = 2;

// keyboard command indentifier
constexpr char KEYBOARD_CMDIDENTIFIER = '@';

// keyboard commands
constexpr uint8_t KEYBOARD_CMD_RESET = 1;
constexpr uint8_t KEYBOARD_CMD_GETVERSION = 2;
constexpr uint8_t KEYBOARD_CMD_SETHOLDTIME = 3;
constexpr uint8_t KEYBOARD_CMD_SETDEBOUNCETIME = 4;
constexpr uint8_t KEYBOARD_CMD_SETAUTOREPEATINTERVAL = 5;
constexpr uint8_t KEYBOARD_CMD_SETFASTAUTOREPEATINTERVAL = 6;
constexpr uint8_t KEYBOARD_CMD_SETFASTAUTOREPEATDELAY = 7;

enum class key_state : uint8_t
{
  idle,
  pressed,
  hold,
  released,
  autorepeat
};

enum class keyboard_event_category : uint8_t
{
  numeric,
  decimal,
  operation,
  function
};

enum class special_keyboard_event : uint8_t
{
  none,
  menu_mode,
  mode_switch
};

class KeyboardHandler
{
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

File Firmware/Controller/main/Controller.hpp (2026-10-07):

// Controller.hpp

// main logic

// Copyright (C) 2020-2026 highvoltglow
// Licensed under the MIT License

#pragma once

#include <Arduino.h>
#include <atomic>
#include <freertos/semphr.h>
#include <freertos/queue.h>
#include <time.h>
#include <Config.h>
#include <FirmwareInfo.h>
#include <DeviceModes.h>
#include <Wire.h>
#include <SerialPrint.h>
#include <Errors.hpp>
#include <KeyboardHandler.hpp>
#include <Helper.hpp>
#include <Settings.hpp>
#include <SettingsCache.hpp>
#include <DisplayHandler.hpp>
#include <Calculator.hpp>
#include <Clock.hpp>
#include <Lighting.hpp>
#include <PIR.hpp>
#include <GPS.hpp>
#include <Temperature.hpp>
#include <MenuHandler.hpp>
#if WEB_SUPPORT
#include <WebServer.hpp>
#include <WebHelper.hpp>
#if CALC_TESTS
#include <CalcTests.hpp>
#endif
#endif

// pin definitions
constexpr uint8_t PIN_HVENABLE = 4;
constexpr uint8_t PIN_HVLED = 5;
constexpr uint8_t PIN_SHIFT = 17;
constexpr uint8_t PIN_STORE = 16;
constexpr uint8_t PIN_DATA = 18;
constexpr uint8_t PIN_BLANK = 19;
constexpr uint8_t PIN_LEDCTL = 14;
constexpr uint8_t PIN_GPSTX = 33;
constexpr uint8_t PIN_GPSRX = 32;
constexpr uint8_t PIN_PIR = 35;
constexpr uint8_t PIN_KINT = 27;
constexpr uint8_t PIN_TEMPERATURE = 25;
constexpr uint8_t PIN_BUTTON1 = 34;
constexpr uint8_t PIN_NETACT = 12;
constexpr uint8_t PIN_RTC = 36;

// controller temperature monitoring
constexpr float SHUTDOWN_TEMP = 50.0;
constexpr float RECOVER_TEMP = 45.0;
constexpr unsigned long TEMP_CHECK_INTERVAL = 10000; // in ms

// minimum allowed time between two high-voltage switch-on events
constexpr unsigned long MIN_HVON_INTERVAL = 1000; // in ms

// how long BUTTON1 must be held down at power-up to trigger a factory reset
constexpr unsigned long FACTORY_RESET_HOLD_TIME = 2500; // in ms

#if OTA_SUPPORT
// how long a firmware update stays armed after [F] + [±] is pressed
constexpr unsigned long OTA_ARM_WINDOW = 5UL * 60UL * 1000UL; // in ms
#endif

// minimum time between web display/LED snapshot broadcasts
constexpr unsigned long DISPLAY_BROADCAST_INTERVAL = 100; // in ms

// struct needed for digit rotation for cathode poisoning prevention
typedef struct
{
  uint8_t rotationStep;
  int rotationInterval;
  unsigned long lastRotationTimestamp;
} ROTATIONDATA;

// struct with state variables
typedef struct
{
  device_mode deviceMode;
  device_mode prevDeviceMode;
  bool highVoltageOn;
  bool autoOff;
  bool temperatureShutdown;
  bool offDayActive;
  bool offDayForceOff;
  bool offDayInitialized;
  bool offWindowActive;
  bool offWindowForceOff;
  bool offWindowInitialized;
  bool dimmingActive;
  bool rotationStopped;
  bool scrollResult;
  bool pendingSettingsIsReset;
#if WEB_SUPPORT
  device_mode lastBroadcastDeviceMode;
  bool deviceModeBroadcastInitialized;
  bool displayDirty;
#endif
} CONTROLLERSTATE;

#if WEB_SUPPORT
// a key event received from the web keypad, queued for processing on the main task
typedef struct
{
  uint8_t keyCode;
  bool functionKeyPressed;
  bool shiftKeyPressed;
} KEYPADEVENT;

// reserved keyCode values sent by the web keypad for commands
constexpr uint8_t KEYPAD_CMD_MODE_SWITCH = 254; // the "Switch Mode" button
constexpr uint8_t KEYPAD_CMD_MENU_MODE = 253;   // the "Menu" button

// a register panel subscription change, queued for processing on the main task
enum class register_sub_event : uint8_t
{
  subscribe,
  unsubscribe,
  reset
};
#endif

class Controller
{
public:
  Controller()
      : _displayHandler(DISPLAY_TYPE, PIN_DATA, PIN_STORE, PIN_SHIFT, PIN_BLANK, PIN_LEDCTL),
        _clock(&_displayHandler, &_settings),
        _lighting(&_displayHandler),
        _pir(PIN_PIR),
        _temperature(PIN_TEMPERATURE),
#if WEB_SUPPORT
        _web(PIN_NETACT, &_settings),
#endif
        _menuHandler(&_settings, _displayHandler.getDecimalSeparatorPosition())

  {
    _state.highVoltageOn = true;
    _hvOnTimestamp = 0;
    _hvOnAccumulatedSeconds = 0;
    _state.autoOff = false;
    _state.offWindowActive = false;
    _offWindowKeyBaseline = 0;
    _state.offWindowForceOff = false;
    _state.offDayForceOff = false;
    _state.offDayActive = false;
    _state.offDayInitialized = false;
    _offDayKeyBaseline = 0;
    _state.offWindowInitialized = false;
    _state.deviceMode = device_mode::calculator;
    _state.prevDeviceMode = device_mode::calculator;
    _rotationData = (ROTATIONDATA *)calloc(_displayHandler.getDigitCount() + MAX_SPECIAL_CHARS_DIGITS, sizeof(ROTATIONDATA));
    _state.rotationStopped = false;
    _state.scrollResult = false;
    _state.temperatureShutdown = false;
    _lastTempCheckTimestamp = millis() - TEMP_CHECK_INTERVAL - 1;
    _lastBoardTemp = TEMP_UNDEFINED;
    _state.dimmingActive = false;
    _settingsUpdateMutex = xSemaphoreCreateMutex();
    _state.pendingSettingsIsReset = false;
#if WEB_SUPPORT
    _keypadEventQueue = xQueueCreate(8, sizeof(KEYPADEVENT));
    _registerSubscriptionQueue = xQueueCreate(8, sizeof(register_sub_event));
    _registerSubscriberCount = 0;
    _state.deviceModeBroadcastInitialized = false;
    _state.displayDirty = false;
    _lastDisplaySnapshot = 0;
    _timeSyncQueue = xQueueCreate(2, sizeof(time_t));
#endif
  }

  virtual ~Controller()
  {
    free(_rotationData);
    vSemaphoreDelete(_settingsUpdateMutex);
#if WEB_SUPPORT
    vQueueDelete(_keypadEventQueue);
    vQueueDelete(_registerSubscriptionQueue);
    vQueueDelete(_timeSyncQueue);
#endif
  }

  // initialize controller
  int begin()
  {
    int result = ERR_SUCCESS;

    // set high voltage off
    pinMode(PIN_HVENABLE, OUTPUT);
    pinMode(PIN_HVLED, OUTPUT);
    hvOFF();

    // define additional pin modes
    pinMode(PIN_NETACT, OUTPUT);
    pinMode(PIN_BUTTON1, INPUT);

    // turn off the network activity LED
    digitalWrite(PIN_NETACT, LOW);

    // BUTTON1 held down (active low) for FACTORY_RESET_HOLD_TIME at power-up triggers a factory reset
    bool factoryReset = isFactoryResetButtonHeld();

    // initialize non-volatile storage
    if (_settings.begin())
    {
      if (factoryReset)
      {
        // erase all stored settings, including the AP password
        _settings.factoryReset();
      }

      // load settings into settings cache
      _settings.readSettings();

      // hide some setting according to display type
      adjustVisibleSettings();

      // general brightness of the LED lighting
      _displayHandler.setLedBrightness(currentLedBrightness());

      // initialize calculator
      _calculator.begin(_displayHandler.getDigitCount(), _displayHandler.getDecimalSeparatorCount(), _displayHandler.hasPlusSign());

      // get notified on long operations
      _calculator.attachLongOperationCb([this](long_operation lo)
                                        { onLongOperation(lo); });

      // initialize display
      _displayHandler.begin();
      _displayHandler.clearDisplay();

      // initialize LED lighting
      _lighting.begin();
      _lighting.off();
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

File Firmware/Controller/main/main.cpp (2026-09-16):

// main.cpp

// Nixie Calculator Firmware

// Copyright (C) 2020-2026 highvoltglow
// Licensed under the MIT License

#include <main.h>

// setup
void setup()
{
  // init serial print for debugging
  __serial_begin(115200);

  // init controller
  int err = controller.begin();
  if (err != ERR_SUCCESS)
  {
    __serial_println("Failed to initialize controller. Error: " +
                     String(err) + " " + Errors::getErrorText(err));
    while (true)
    {
      // yield so the idle task can run and the watchdog doesn't reboot us
      delay(1000);
    }
  }
  __serial_println("Controller initialized successfully");
}

// main loop
void loop()
{
  controller.process();
  delay(5); // keep watchdog happy
}

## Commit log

2026-09-16 fixed infinite recursion in ratpowi32 if power = INT_MIN
2026-09-26 Update RELEASE_NOTES for version 0.11.2
    Added new features including a clock mode and LED brightness settings.
2026-09-26 Swap descriptions for timer and stopwatch modes
